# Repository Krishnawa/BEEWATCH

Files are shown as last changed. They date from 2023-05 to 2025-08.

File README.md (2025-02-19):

BEEWATCH

## Cloning the Repository and Updating Submodules  

To properly set up this project, follow these steps:  

### 1. Clone the Repository  
Use the `--recurse-submodules` flag to clone the repository along with its submodules:  

```sh
git clone --recurse-submodules https://github.com/Krishnawa/BEEWATCH.git
```
If you have already cloned the repository without submodules, initialize and update them manually:
```sh
git submodule update --init --recursive --remote
```

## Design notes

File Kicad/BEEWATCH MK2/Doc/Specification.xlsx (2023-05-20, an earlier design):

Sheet: Sheet1
ESP32-D0WDQ6 | Specifications
Processor | Dual-core Tensilica LX6 microprocessor with clock speed up to 240 MHz
Memory | 520 KB SRAM
 | 448 KB ROM
 | 8 KB RTC SRAM
WiFi | 802.11 b/g/n
 | Wi-Fi Direct (P2P), soft-AP
 | Integrated TCP/IP protocol stack
Bluetooth | Bluetooth v4.2 BR/EDR and BLE
 | Hardware acceleration for AES, SHA-2, and RSA
 | Secure boot feature
 | Flash encryption and secure flash
Peripheral interfaces | 12-bit SAR ADC up to 18 channels
 | 34 × programmable GPIOs
 | 2 × 8-bit DACs
 | 10 × touch sensors
 | 4 × SPI
 | 2 × I²C
 | 3 × UART
 | 2 × I²S
 | 16 × PWM
 | USB 2.0 (device mode only)
 | CAN 2.0
 | Ethernet MAC interface with dedicated DMA and IEEE 1588 support (available on some modules)
Power management | Internal low-dropout regulator
 | Individual power domain for RTC
 | Five different power modes
Operating temperature range | -40°C to +85°C

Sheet: Sheet3
Pin Name | Pin Number | Functionality
VDDA | 1 | Analog power supply (2.3 V ∼ 3.6 V)
LNA_IN | 2 | RF input and output
VDD3P3 | 3 | Analog power supply (2.3 V ∼ 3.6 V)
VDD3P3 | 4 | Analog power supply (2.3 V ∼ 3.6 V)
SENSOR_VP | 5 | GPIO36, ADC1_CH0, RTC_GPIO0
SENSOR_CAPP | 6 | GPIO37, ADC1_CH1, RTC_GPIO1
SENSOR_CAPN | 7 | GPIO38, ADC1_CH2, RTC_GPIO2
SENSOR_VN | 8 | GPIO39, ADC1_CH3, RTC_GPIO3
CHIP_PU | 9 | High: On; enables the chip Low: Off; the chip powers off Note: Do not leave the CHIP_PU pin floating.
VDET_1 | 10 | GPIO34, ADC1_CH6, RTC_GPIO4
VDET_2 | 11 | GPIO35, ADC1_CH7, RTC_GPIO5
32K_XP | 12 | GPIO32, ADC1_CH4, RTC_GPIO9, TOUCH9, 32K_XP (32.768 kHz crystal oscillator input)
32K_XN | 13 | GPIO33, ADC1_CH5, RTC_GPIO8, TOUCH8, 32K_XN (32.768 kHz crystal oscillator output)
GPIO25 | 14 | GPIO25, ADC2_CH8, RTC_GPIO6, DAC_1, EMAC_RXD0
GPIO26 | 15 | GPIO26, ADC2_CH9, RTC_GPIO7, DAC_2, EMAC_RXD1
GPIO27 | 16 | GPIO27, ADC2_CH7, RTC_GPIO17, TOUCH7, EMAC_RX_DV
MTMS | 17 | GPIO14, ADC2_CH6, RTC_GPIO16, TOUCH6, EMAC_TXD2, HSPICLK, HS2_CLK, SD_CLK, MTMS | CLK | Antenna out
MTDI | 18 | GPIO12, ADC2_CH5, RTC_GPIO15, TOUCH5, EMAC_TXD3, HSPIQ, HS2_DATA2, SD_DATA2, MTDI | MISO | Power input
VDD3P3_RTC | 19 | Input power supply for RTC IO (2.3 V ∼ 3.6 V) |  | Input Pin only
MTCK | 20 | GPIO13, ADC2_CH4, RTC_GPIO14, TOUCH4, EMAC_RX_ER, HSPID, HS2_DATA3, SD_DATA3, MTCK | MOSI | QSPI Flash
MTDO | 21 | GPIO15, ADC2_CH3, RTC_GPIO13, TOUCH3, EMAC_RXD3, HSPICS0. HS2_CMD, SD_CMD,MTDO | CS | RTC GPIOs, These RTC GPIOs can be used to wake up the ESP32 from deep sleep when the Ultra Low Power (ULP) co-processor is running.
GPIO2 | 22 | GPIO2, ADC2_CH2, RTC_GPIO12, TOUCH2, HSPIWP, HS2_DATA0, SD_DATA0 |  | 2 x 8 bits DAC
GPIO0 | 23 | GPIO0, ADC2_CH1, RTC_GPIO11, TOUCH1, EMAC_TX_CLK, CLK_OUT1, |  | PWM will not available
GPIO4 | 24 | GPIO4, ADC2_CH0, RTC_GPIO10, TOUCH0, EMAC_TX_ER, HSPIHD, HS2_DATA1, SD_DATA1
GPIO16 | 25 | GPIO16, HS1_DATA4, U2RXD,EMAC_CLK_OUT
VDD_SDIO | 26 | Output power supply: 1.8 V or the same voltage as VDD3P3_RTC
GPIO17 | 27 | GPIO17, HS1_DATA5, U2TXD, EMAC_CLK_OUT_180
SD_DATA_2 | 28 | GPIO9, HS1_DATA2, U1RXD, SD_DATA2, SPIHD
SD_DATA_3 | 29 | GPIO10, HS1_DATA3, U1TXD, SD_DATA3, SPIWP
IO27 | 30 | GPIO11, HS1_CMD, U1RTS, SD_CMD, SPICS0
IO34 | 31 | GPIO6, HS1_CLK, U1CTS, SD_CLK, SPICLK
SD_DATA_0 | 32 | GPIO7, HS1_DATA0, U2RTS, SD_DATA0, SPIQ
SD_DATA_1 | 33 | GPIO8, HS1_DATA1, U2CTS, SD_DATA1, SPID
GPIO5 | 34 | GPIO5, HS1_DATA6, VSPICS0, EMAC_RX_CLK
GPIO18 | 35 | GPIO18, HS1_DATA7, VSPICLK
GPIO23 | 36 | GPIO23, HS1_STROBE, VSPID
VDD3P3_CPU | 37 | Input power supply for CPU IO (1.8 V ∼ 3.6 V)
GPIO19 | 38 | GPIO19, U0CTS, VSPIQ, EMAC_TXD0
GPIO22 | 39 | GPIO22, U0RTS, VSPIWP, EMAC_TXD1
U0RXD | 40 | GPIO3, U0RXD, CLK_OUT2
U0TXD | 41 | GPIO1, U0TXD, CLK_OUT3, EMAC_RXD2
GPIO21 | 42 | GPIO21, VSPIHD, EMAC_TX_EN
VDDA | 43 | Analog power supply (2.3 V ∼ 3.6 V)
XTAL_N | 44 | External crystal output
XTAL_P | 45 | External crystal input
VDDA | 46 | Analog power supply (2.3 V ∼ 3.6 V)
CAP2 | 47 | Connects to a 3.3 nF (10%) capacitor and 20 kΩ resistor in parallel to CAP1
CAP1 | 48 | Connects to a 10 nF series capacitor to ground
GND | 49 | Ground

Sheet: Sheet2
REQ_NO | Requirement Specification | REQ_NO | REQ_NO | Requirement Specification
PRD_REQ_1 | The product shall use rounded LCD/OLED Display | PRD_REQ_1 | COMP_REQ_1 | Use GC9A01 1.28 inch 240*240 IPS LCD (SPI)
PRD_REQ_2 | The Product shall require GPS | PRD_REQ_2 | COMP_REQ_2 | Not includin in the first phase
PRD_REQ_3 | The Product shall require RTC | PRD_REQ_3 | COMP_REQ_3 | Will use Network Time Protocol
PRD_REQ_4 | In the first phase of this product need to show the time only | PRD_REQ_4 | COMP_REQ_4
PRD_REQ_5 | The Product shall require small buzzer | PRD_REQ_5 | COMP_REQ_5 | Find the PN
PRD_REQ_6 | The product shall use a chip with Wi-Fi and BT | PRD_REQ_6 | COMP_REQ_6 | will use ESP32-D0WDQ6 QFN 6*6 also find the PN
PRD_REQ_7 | The product shall have 2 push button | PRD_REQ_7 | COMP_REQ_7 | Find the PN
PRD_REQ_8 | The product shall have an accelerometer | PRD_REQ_8 | COMP_REQ_8 | MPU6050
PRD_REQ_9 | The product shall have an Temperature sensor | PRD_REQ_9 | COMP_REQ_9 | LM35
PRD_REQ_10 | The Product shall be small as Possible | PRD_REQ_10 | COMP_REQ_10 | Antenna size will be smalll
PRD_REQ_11 | The product shall have at least one week battery backup | PRD_REQ_11 | COMP_REQ_11 | 300mAh If possible
PRD_REQ_12 | The product shall have a fuel gauge | PRD_REQ_12 | COMP_REQ_12 | MAX17260,MAX17048
PRD_REQ_13 | The product shall have a charger | PRD_REQ_13 | COMP_REQ_13 | TP4056
PRD_REQ_14 | The product shall have aesthetic case | PRD_REQ_14 | COMP_REQ_14
PRD_REQ_15 |  | PRD_REQ_15 | COMP_REQ_15
PRD_REQ_16 |  | PRD_REQ_16 | COMP_REQ_16
PRD_REQ_17 |  | PRD_REQ_17 | COMP_REQ_17
PRD_REQ_18 |  | PRD_REQ_18 | COMP_REQ_18
PRD_REQ_19 |  | PRD_REQ_19 | COMP_REQ_19
PRD_REQ_20 |  | PRD_REQ_20 | COMP_REQ_20

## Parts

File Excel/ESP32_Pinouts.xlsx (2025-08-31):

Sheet: IO MUX Pin Functions
No. | Name |  |  | Type | Power | At Reset | After Reset | IO MUX | RTC | Analog
1 | LNA_IN |  |  | Analog
2 | VDD3P3 |  |  | Power
3 | VDD3P3 |  |  | Power
4 | CHIP_PU |  |  | Analog | VDD3P3_RTC |  |  |  |  |  | · IE – input enabled
5 | GPIO0 | SWITCH1 |  | IO | VDD3P3_RTC | IE, WPU | IE, WPU | IO MUX | RTC |  | · WPU – internal weak pull-up resistor enabled
6 | GPIO1 | SWITCH2 |  | IO | VDD3P3_RTC | IE | IE | IO MUX | RTC | Analog | · WPD – internal weak pull-down resistor enabled
7 | GPIO2 | BUZZER_EN |  | IO | VDD3P3_RTC | IE | IE | IO MUX | RTC | Analog | · USB_PU – USB pull-up resistor enabled
8 | GPIO3 | SDA |  | IO | VDD3P3_RTC | IE | IE | IO MUX | RTC | Analog
9 | GPIO4 | SCL |  | IO | VDD3P3_RTC |  |  | IO MUX | RTC | Analog
10 | GPIO5 | GPS ENABLE | GPS_EN | IO | VDD3P3_RTC |  |  | IO MUX | RTC | Analog
11 | GPIO6 | GPS RESET | GPS_RST | IO | VDD3P3_RTC |  |  | IO MUX | RTC | Analog
12 | GPIO7 | 1PPS | GPS_PPS | IO | VDD3P3_RTC |  |  | IO MUX | RTC | Analog
13 | GPIO8 | Display | RST | IO | VDD3P3_RTC |  |  | IO MUX | RTC | Analog | ide of the digital an
14 | GPIO9 | Display | DC | IO | VDD3P3_RTC |  | IE | IO MUX | RTC | Analog
15 | GPIO10 | Display | CS | IO | VDD3P3_RTC |  | IE | IO MUX | RTC | Analog
16 | GPIO11 | Display | MOSI | IO | VDD3P3_RTC |  | IE | IO MUX | RTC | Analog
17 | GPIO12 | Display | SCK | IO | VDD3P3_RTC |  | IE | IO MUX | RTC | Analog
18 | GPIO13 | mpu interrupt | MPU_INT | IO | VDD3P3_RTC |  | IE | IO MUX | RTC | Analog
19 | GPIO14 | BAT_VSENSE |  | IO | VDD3P3_RTC |  | IE | IO MUX | RTC | Analog
20 | VDD3P3_RTC |  |  | Power
21 | XTAL_32K_P | XTAL | rtc | IO | VDD3P3_RTC |  |  | IO MUX | RTC | Analog
22 | XTAL_32K_N | XTAL | rtc | IO | VDD3P3_RTC |  |  | IO MUX | RTC | Analog
23 | GPIO17 | GPS RX |  | IO | VDD3P3_RTC |  | IE | IO MUX | RTC | Analog
24 | GPIO18 | GPS TX |  | IO | VDD3P3_RTC |  | IE | IO MUX | RTC | Analog
25 | GPIO19 | USB+ |  | IO | VDD3P3_RTC |  |  | IO MUX | RTC | Analog
26 | GPIO20 | USB- |  | IO | VDD3P3_RTC | USB_PU | USB_PU | IO MUX | RTC | Analog
27 | GPIO21 | LED2 |  | IO | VDD3P3_RTC |  |  | IO MUX | RTC
28 | SPICS1 |  |  | IO | VDD_SPI | IE, WPU | IE, WPU | IO MUX
29 | VDD_SPI |  |  | Power
30 | SPIHD |  |  | IO | VDD_SPI | IE, WPU | IE, WPU | IO MUX
31 | SPIWP |  |  | IO | VDD_SPI | IE, WPU | IE, WPU | IO MUX
32 | SPICS0 |  |  | IO | VDD_SPI | IE, WPU | IE, WPU | IO MUX
33 | SPICLK |  |  | IO | VDD_SPI | IE, WPU | IE, WPU | IO MUX
34 | SPIQ |  |  | IO | VDD_SPI | IE, WPU | IE, WPU | IO MUX
35 | SPID |  |  | IO | VDD_SPI | IE, WPU | IE, WPU | IO MUX
36 | SPICLK_N |  |  | IO | VDD_SPI / VDD3P3_CPU | IE | IE | IO MUX
37 | SPICLK_P |  |  | IO | VDD_SPI / VDD3P3_CPU | IE | IE | IO MUX
38 | GPIO33 |  |  | IO | VDD_SPI / VDD3P3_CPU |  | IE | IO MUX
39 | GPIO34 | PWR SENSE |  | IO | VDD_SPI / VDD3P3_CPU |  | IE | IO MUX
40 | GPIO35 | BUZZER |  | IO | VDD_SPI / VDD3P3_CPU |  | IE | IO MUX
41 | GPIO36 |  |  | IO | VDD_SPI / VDD3P3_CPU |  | IE | IO MUX
42 | GPIO37 |  |  | IO | VDD_SPI / VDD3P3_CPU |  | IE | IO MUX
43 | GPIO38 |  |  | IO | VDD3P3_CPU |  | IE | IO MUX
44 | MTCK |  |  | IO | VDD3P3_CPU |  | IE | IO MUX
45 | MTDO |  |  | IO | VDD3P3_CPU |  | IE | IO MUX
46 | VDD3P3_CPU |  |  | Power
47 | MTDI |  |  | IO | VDD3P3_CPU |  | IE | IO MUX
48 | MTMS |  |  | IO | VDD3P3_CPU |  | IE | IO MUX
49 | U0TXD |  |  | IO | VDD3P3_CPU | IE, WPU | IE, WPU | IO MUX
50 | U0RXD |  |  | IO | VDD3P3_CPU | IE, WPU | IE, WPU | IO MUX
51 | GPIO45 |  |  | IO | VDD3P3_CPU | IE, WPD | IE, WPD | IO MUX
52 | GPIO46 |  |  | IO | VDD3P3_CPU | IE, WPD | IE, WPD | IO MUX
53 | XTAL_N | Crystal |  | Analog
54 | XTAL_P | Crystal |  | Analog
55 | VDDA |  |  | Power
56 | VDDA |  |  | Power
57 | GND |  |  | Power

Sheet: Sheet1
https://chatgpt.com/share/6789162e-64f8-800f-9e0a-48cd8099282f
OPEN TERACE | $GPRMC,155304.00,A,1259.7372,N,07743.0398,E,0.0,0.0,160125,,,A,V*28
CLOSED ROOM | $GNRMC,162906.00,V,1259.7389,N,07743.0415,E,,,160125,,,N,V*24

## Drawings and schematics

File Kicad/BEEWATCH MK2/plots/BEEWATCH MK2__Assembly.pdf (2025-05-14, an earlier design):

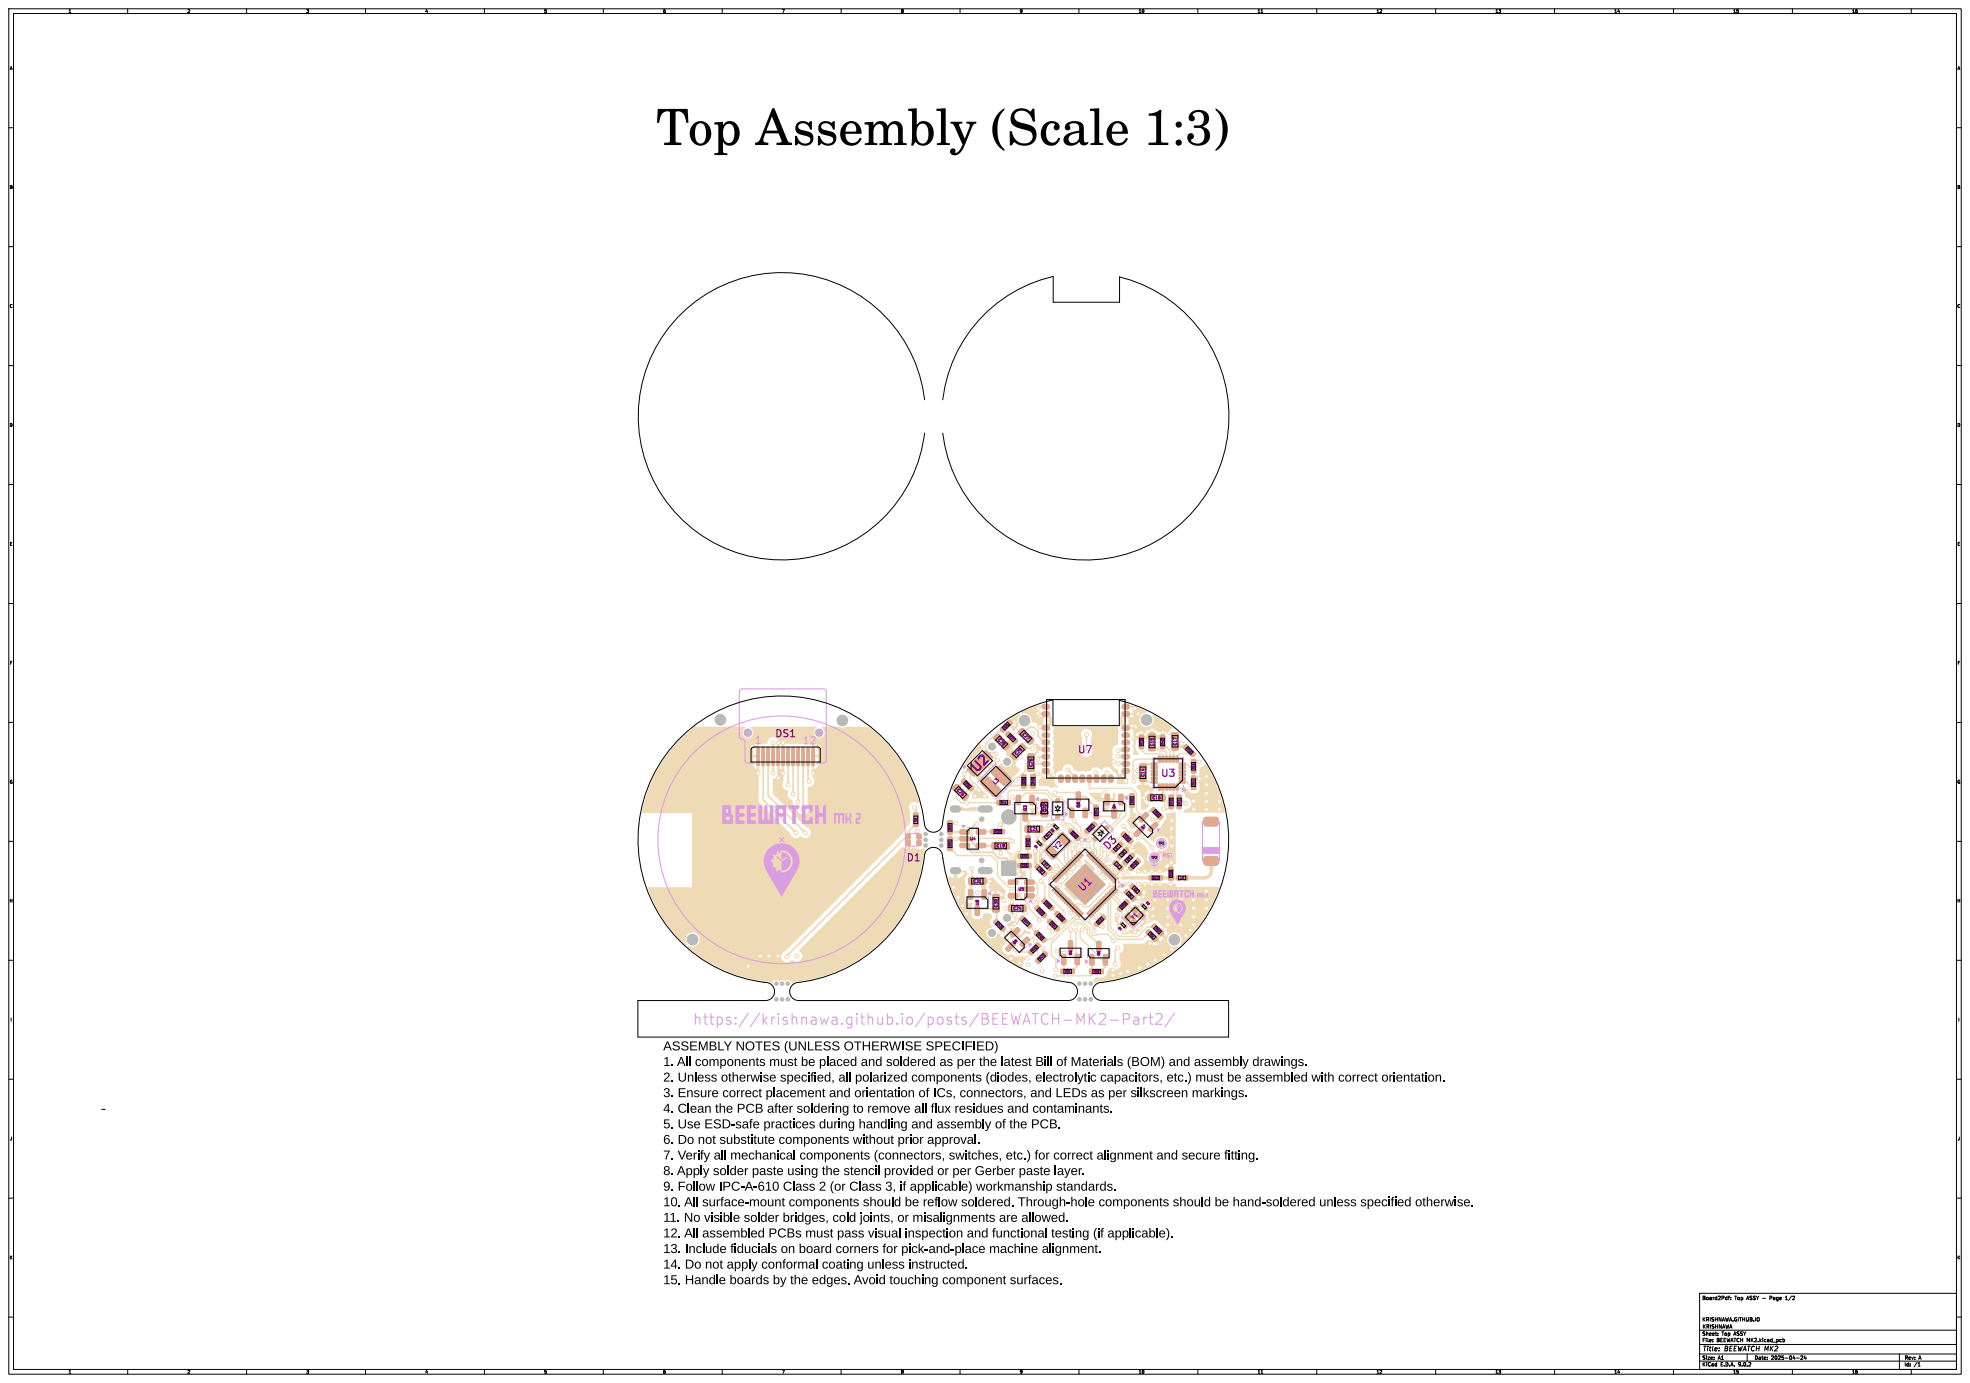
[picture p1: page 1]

RST https://krishnawa.github.io/posts/BEEWATCH-MK2-Part2/

KRISHNAWA.GITHUB.IO
File: BEEWATCH MK2.kicad_pcb Sheet: Top ASSY KRISHNAWA

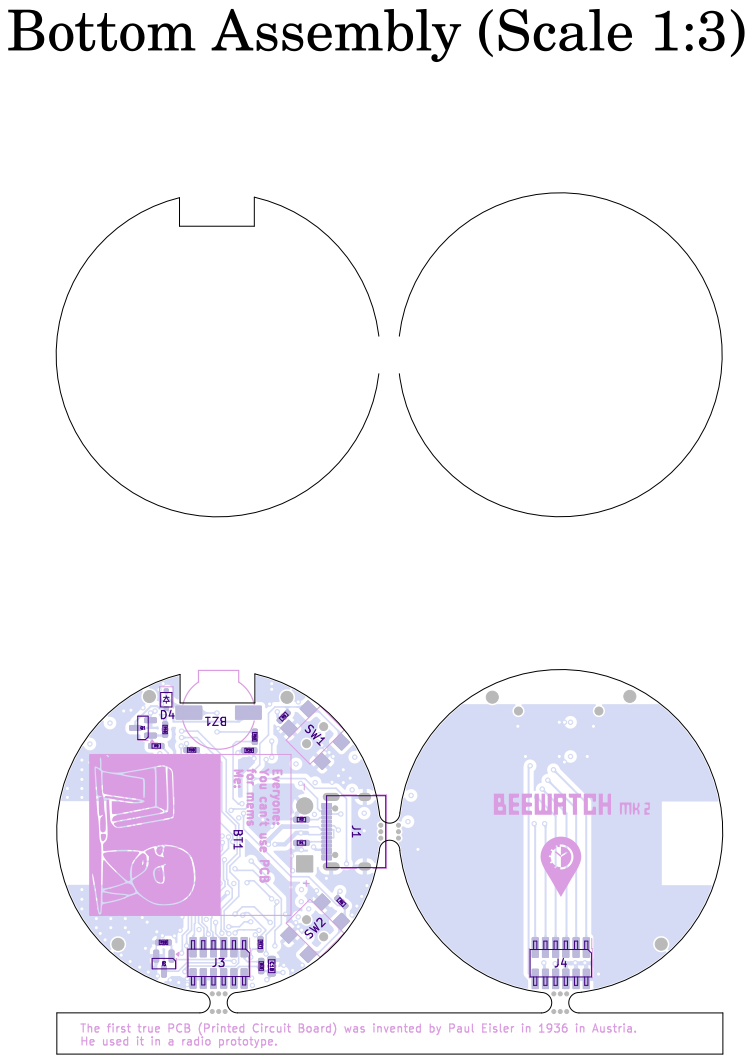
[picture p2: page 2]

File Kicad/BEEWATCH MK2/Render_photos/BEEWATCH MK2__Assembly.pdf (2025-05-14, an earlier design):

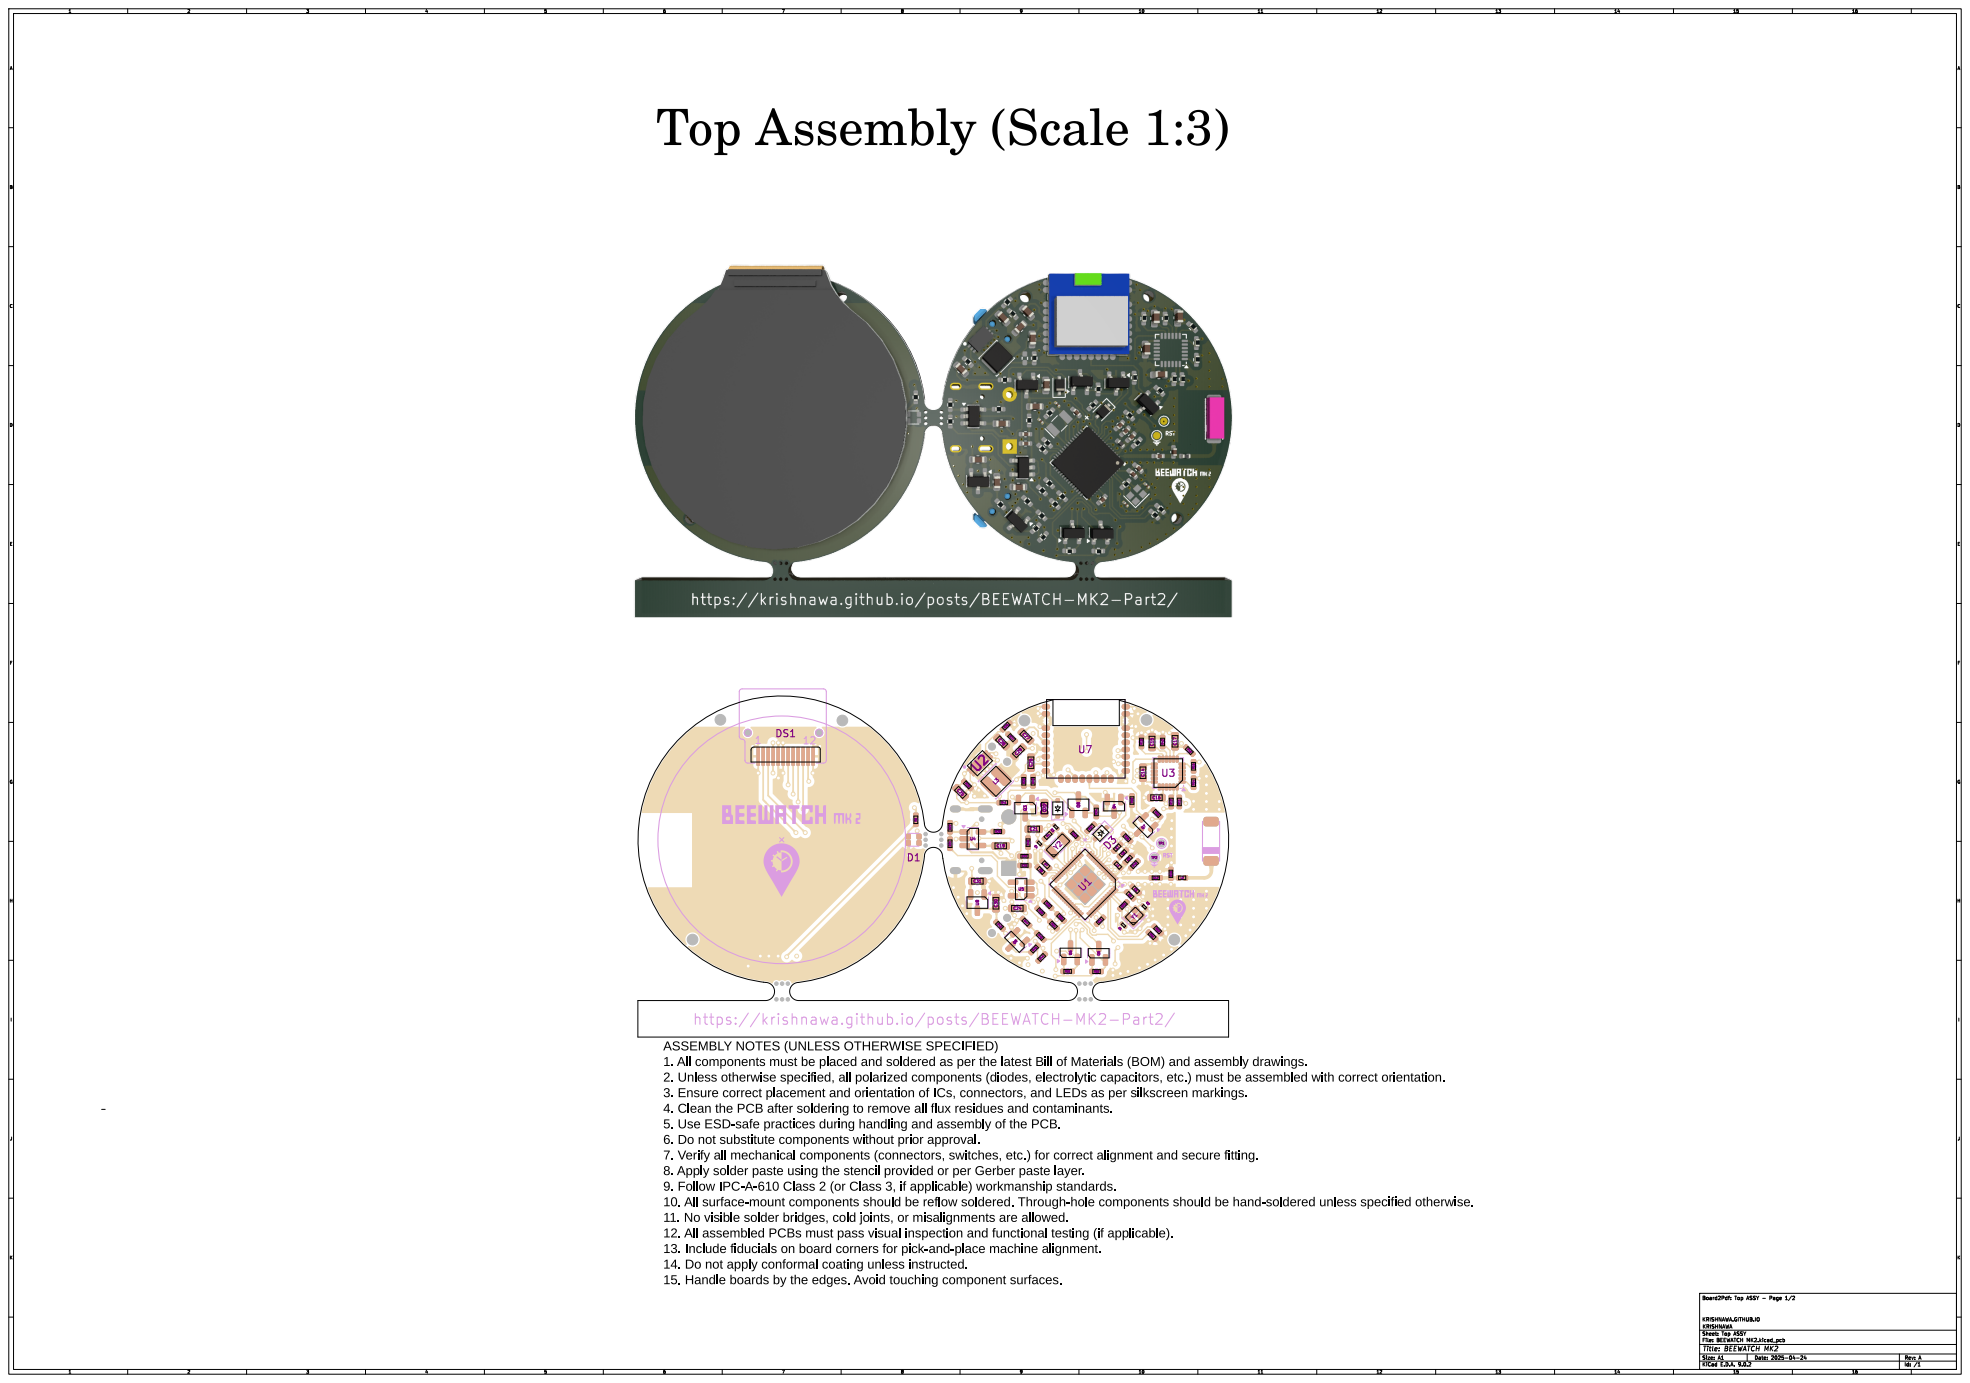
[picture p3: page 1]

RST https://krishnawa.github.io/posts/BEEWATCH-MK2-Part2/

KRISHNAWA.GITHUB.IO
File: BEEWATCH MK2.kicad_pcb Sheet: Top ASSY KRISHNAWA

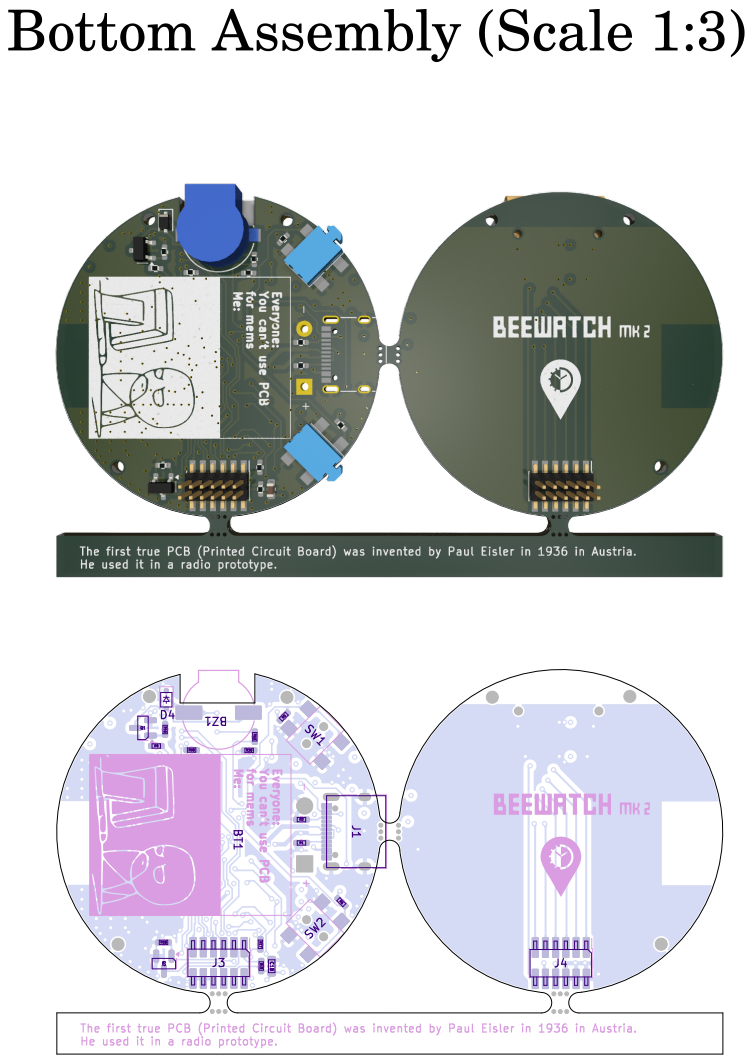
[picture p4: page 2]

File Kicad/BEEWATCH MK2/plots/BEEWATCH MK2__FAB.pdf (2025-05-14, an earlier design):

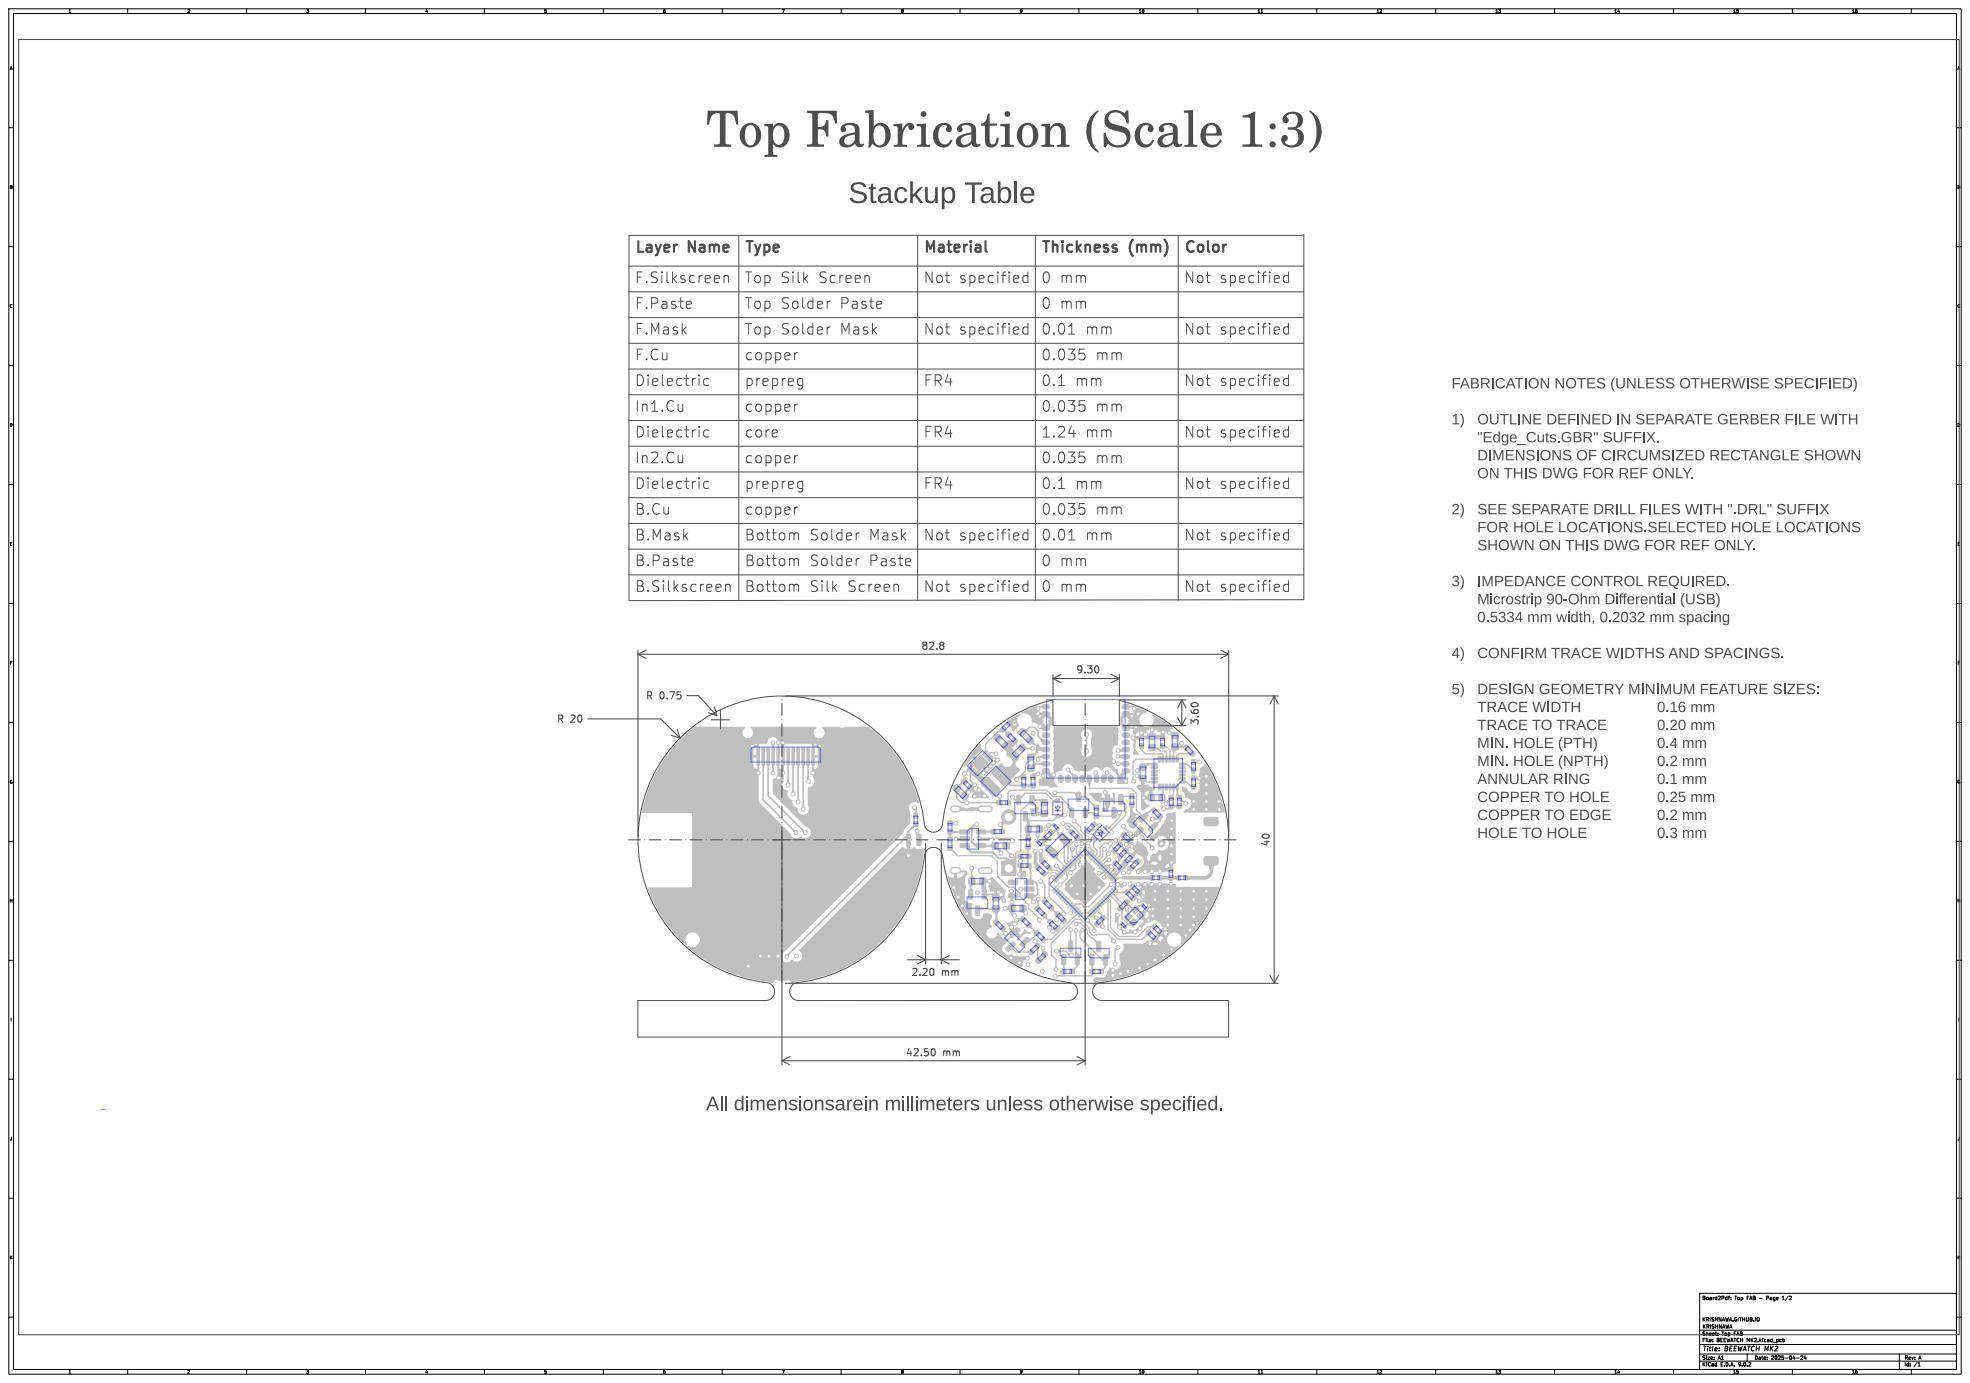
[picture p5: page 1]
IJK; IJK Date: 2025-04-24 KiCad; E.D.A. 9.0.2 Size: A1; Rev: A; File: BEEWATCH; MK2.kicad_pcb Sheet: Top; FAB KRISHNAWA; Board2Pdf:; Top; FAB -; Page; Bottom; Silk; Screen; Solder; Mask; Top Solder; prepreg; In1.Cu Dielectric; Not; specified; copper

Layer Name
F.Silkscreen | Top Silk Screen F.Mask | Not specified | 0.1 mm

prepreg F.Paste | | 1.24 mm | Not Not Color Top Solder Paste Not specified specified Material specified Dielectric

Type | Not specified | Thickness | (mm) 0.01 mm | Not specified

Dielectric F.Cu B.Silkscreen | copper | | 0 mm

core | 0.035 mm | Not specified

copper B.Mask | | | | | 0.1 mm

B.Cu | | | 0.035 mm | Not specified

Not specified Bottom Solder Paste | 0.01 mm

B.Paste | | | | | 0 mm

Not specified

KRISHNAWA.GITHUB.IO

Id: /1 Title: BEEWATCH MK2

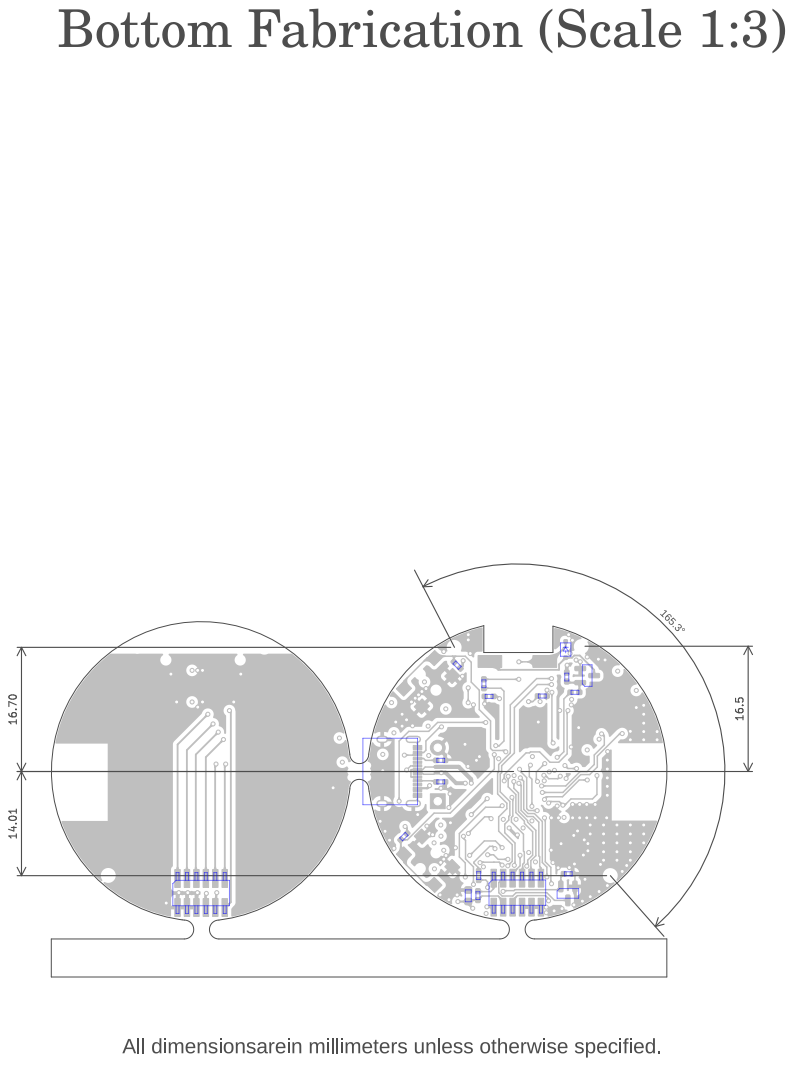
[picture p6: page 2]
IJK; IJK Date: 2025-04-24 KiCad; E.D.A. 9.0.2 Size: A1; Rev: A; File: BEEWATCH; MK2.kicad_pcb Sheet: Bttom; FAB KRISHNAWA; Board2Pdf:; Bttom; FAB -; Page 2/2 14.01

KRISHNAWA.GITHUB.IO

Id: /1 Title: BEEWATCH MK2

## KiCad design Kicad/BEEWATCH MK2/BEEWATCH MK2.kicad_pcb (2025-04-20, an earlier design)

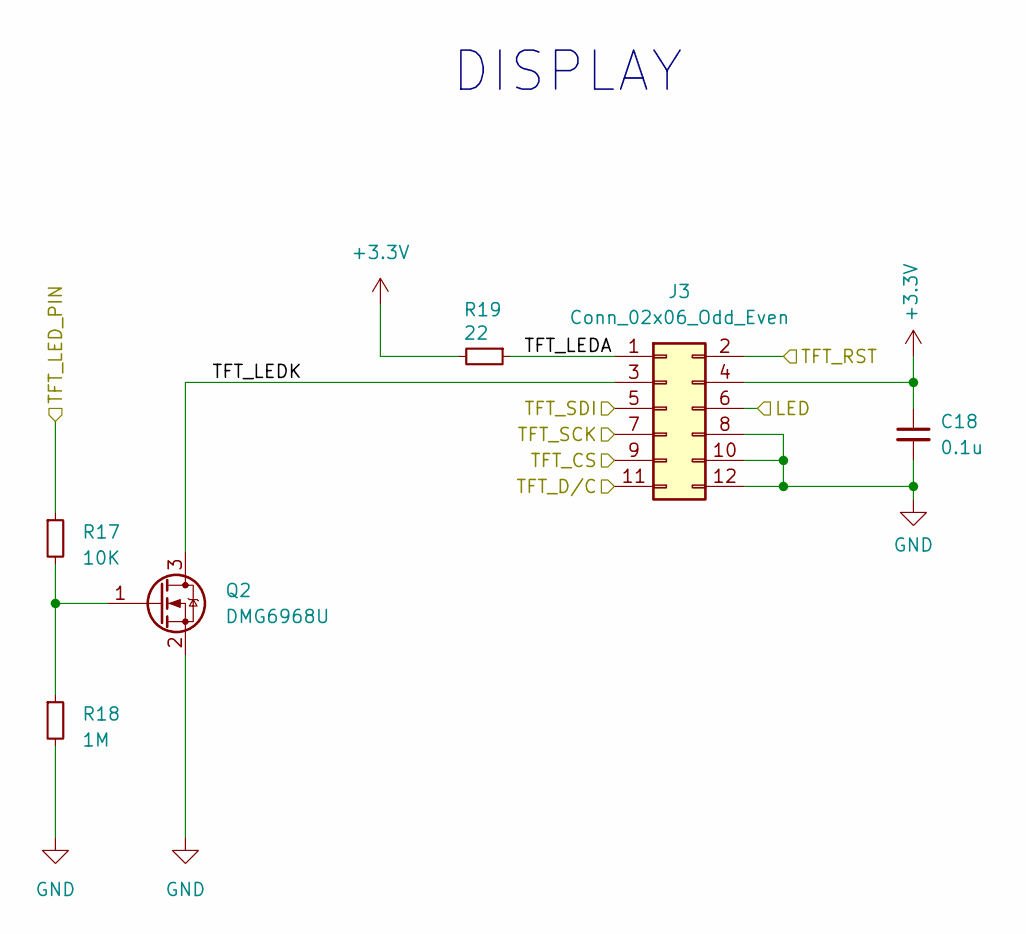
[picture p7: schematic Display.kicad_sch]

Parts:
C18: 0.1u; C_0603_1608Metric
J3: Conn_02x06_Odd_Even; PinHeader_2x06_P1.27mm_Vertical_SMD
Q2: DMG6968U; SOT-23
R17: 10K; R_0402_1005Metric_Pad0.72x0.64mm_HandSolder
R18: 1M; R_0402_1005Metric_Pad0.72x0.64mm_HandSolder
R19: 22; R_0402_1005Metric_Pad0.72x0.64mm_HandSolder

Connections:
+3.3V: C18.1, J3.4, R19.2; also elsewhere on the board
/Display/LED: J3.6; also elsewhere on the board
/Display/TFT_CS: J3.9; also elsewhere on the board
/Display/TFT_D/C: J3.11; also elsewhere on the board
/Display/TFT_LEDA: J3.1, R19.1
/Display/TFT_LEDK: J3.3, Q2.3 (D)
/Display/TFT_LED_PIN: R17.1; also elsewhere on the board
/Display/TFT_RST: J3.2; also elsewhere on the board
/Display/TFT_SCK: J3.7; also elsewhere on the board
/Display/TFT_SDI: J3.5; also elsewhere on the board
GND: C18.2, J3.8, J3.10, J3.12, Q2.2 (S), R18.2; also elsewhere on the board
unnamed: Q2.1 (G), R17.2, R18.1

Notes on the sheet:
DISPLAY

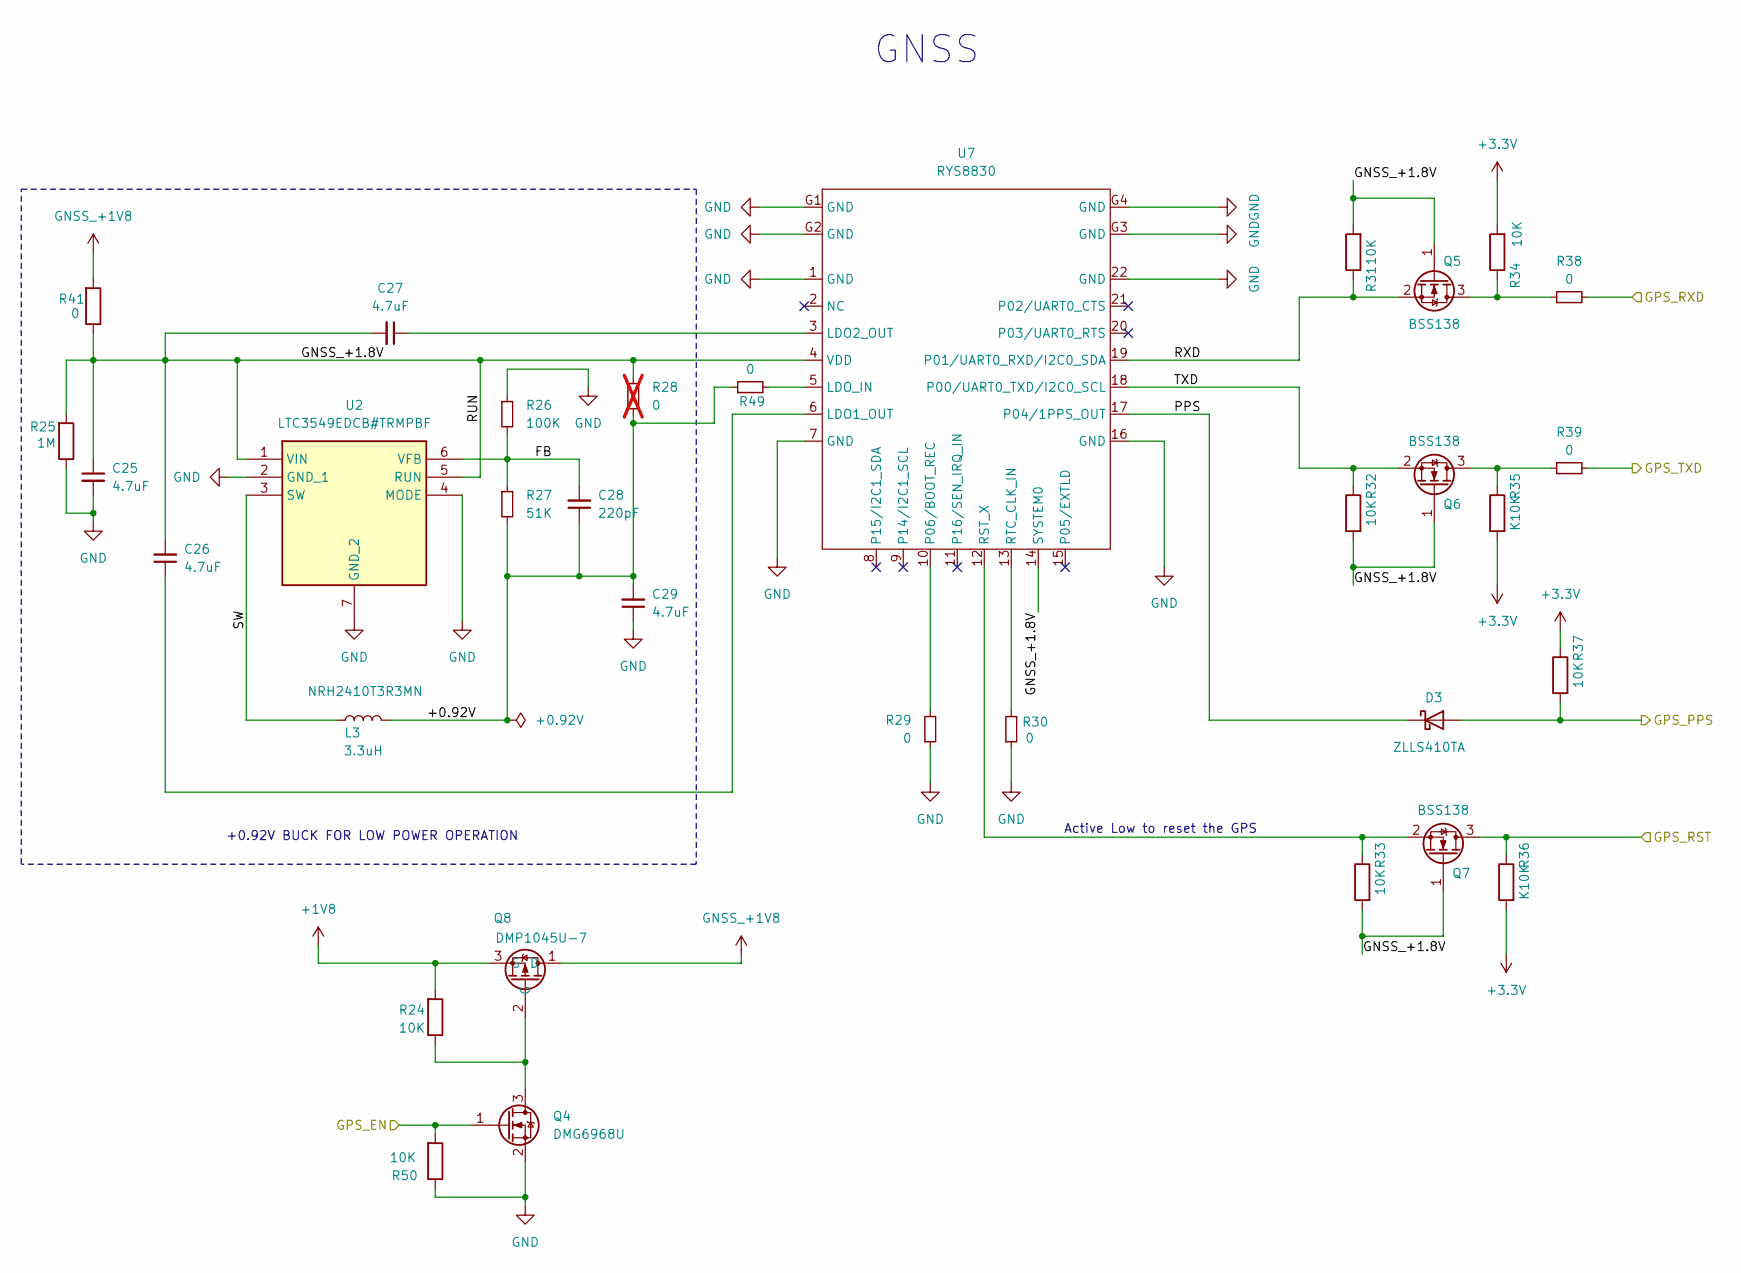
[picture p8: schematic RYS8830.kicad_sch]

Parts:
C25, C26, C27, C29: 4.7uF; C_0603_1608Metric
C28: 220pF; C_0603_1608Metric
D3: ZLLS410TA; D_SOD-323F
L3: 3.3uH; L_Cenker_CKCS3012; MPN NRH2410T3R3MN
Q4: DMG6968U; SOT-23
Q5, Q6, Q7: BSS138; SOT-23
Q8: DMP1045U-7; SOT-23-3
R24, R31, R32, R33, R34, R37, R50: 10K; R_0402_1005Metric_Pad0.72x0.64mm_HandSolder
R25: 1M; R_0402_1005Metric_Pad0.72x0.64mm_HandSolder
R26: 100K; R_0402_1005Metric_Pad0.72x0.64mm_HandSolder
R27: 51K; R_0402_1005Metric_Pad0.72x0.64mm_HandSolder
R28: 0; R_0402_1005Metric_Pad0.72x0.64mm_HandSolder; not fitted
R29, R30, R38, R39, R41, R49: 0; R_0402_1005Metric_Pad0.72x0.64mm_HandSolder
R35, R36: K10K; R_0402_1005Metric_Pad0.72x0.64mm_HandSolder
U2: LTC3549EDCB#TRMPBF; SON50P300X200X80-7N-D
U7: RYS8830

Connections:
+1V8: Q8.3 (S), R24.2; also elsewhere on the board
+3.3V: R34.2, R35.2, R36.2, R37.1; also elsewhere on the board
/ESP32/GPS_EN: Q4.1 (G), R50.2; also elsewhere on the board
/ESP32/GPS_PSS: D3.2 (A), R37.2; also elsewhere on the board
/ESP32/GPS_RST: Q7.3 (D), R36.1; also elsewhere on the board
/ESP32/GPS_RXD: R39.2; also elsewhere on the board
/ESP32/GPS_TXD: R38.2; also elsewhere on the board
/RYS8830/+0.92V: C28.1, C29.2, L3.2, R27.2, R28.2, R49.1
/RYS8830/FB: C28.2, R26.2, R27.1, U2.6 (VFB)
/RYS8830/GNSS_+1.8V: C25.1, C26.2, C27.2, Q5.1 (G), Q6.1 (G), Q7.1 (G), R25.2, R28.1, R31.2, R32.2, R33.2, R41.1, U2.1 (VIN), U2.5 (RUN), U7.4 (VDD), U7.14 (SYSTEM0)
/RYS8830/PPS: D3.1 (K), U7.17 (P04/1PPS_OUT)
/RYS8830/RXD: Q5.2 (S), R31.1, U7.19 (P01/UART0_RXD/I2C0_SDA)
/RYS8830/SW: L3.1, U2.3 (SW)
/RYS8830/TXD: Q6.2 (S), R32.1, U7.18 (P00/UART0_TXD/I2C0_SCL)
GND: C25.2, C29.1, Q4.2 (S), R25.1, R26.1, R29.1, R30.1, R50.1, U2.2 (GND_1), U2.4 (MODE), U2.7 (GND_2), U7.1 (GND), U7.7 (GND), U7.16 (GND), U7.22 (GND), U7.G1 (GND), U7.G2 (GND), U7.G3 (GND), U7.G4 (GND); also elsewhere on the board
GNSS_+1V8: Q8.1 (D), R41.2
unnamed: Q4.3 (D), Q8.2 (G), R24.1
unnamed: Q5.3 (D), R34.1, R38.1
unnamed: Q6.3 (D), R35.1, R39.1
unnamed: Q7.2 (S), R33.1, U7.12 (RST_X)
unnamed: C26.1, U7.6 (LDO1_OUT)
unnamed: C27.1, U7.3 (LDO2_OUT)
unnamed: R49.2, U7.5 (LDO_IN)
unnamed: R29.2, U7.10 (P06/BOOT_REC)
unnamed: R30.2, U7.13 (RTC_CLK_IN)

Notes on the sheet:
GNSS
Active Low to reset the GPS
+0.92V BUCK FOR LOW POWER OPERATION

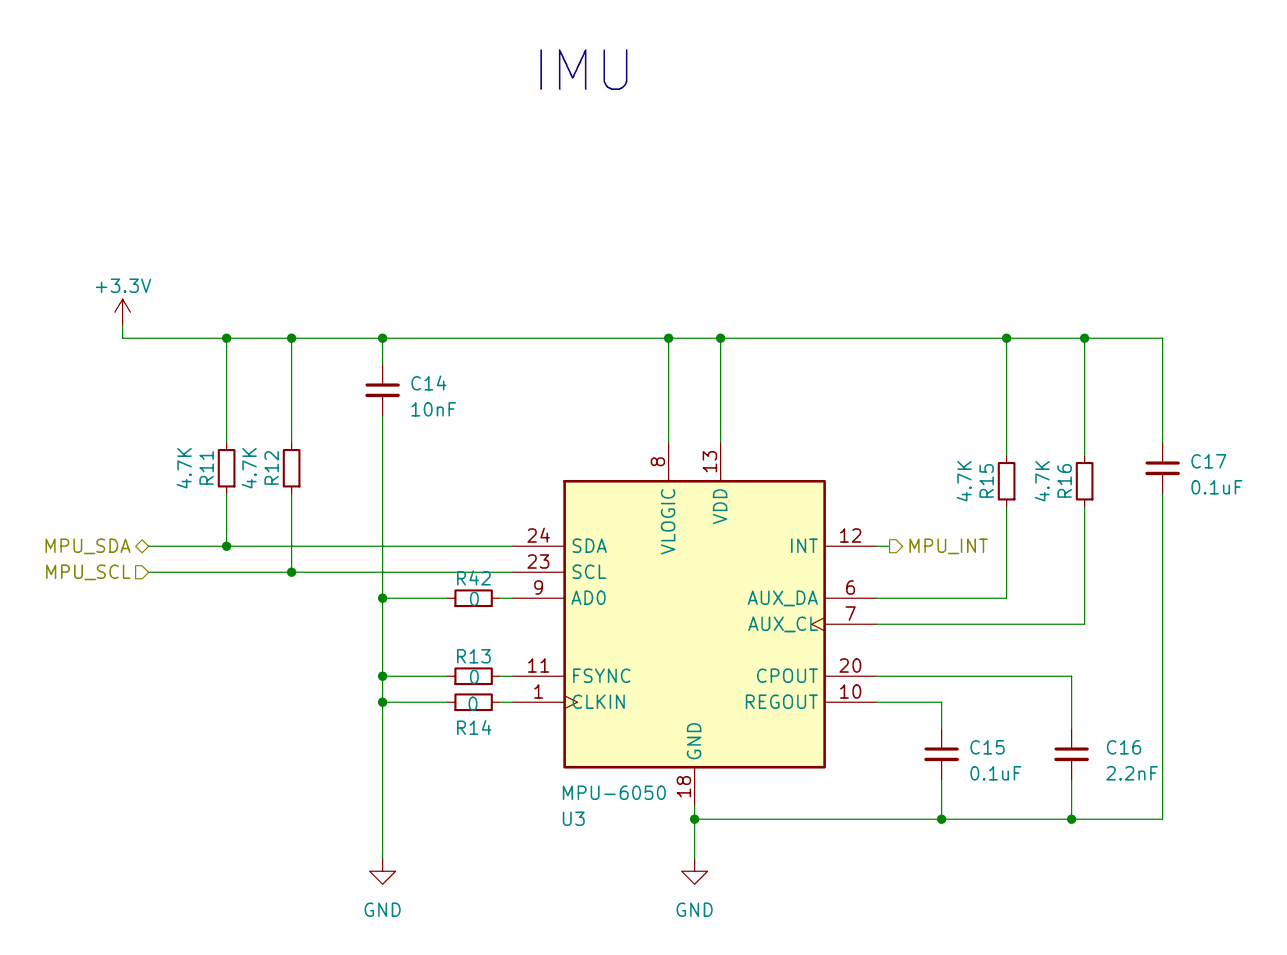
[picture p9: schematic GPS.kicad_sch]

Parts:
C14: 10nF; C_0603_1608Metric
C15, C17: 0.1uF; C_0603_1608Metric
C16: 2.2nF; C_0603_1608Metric
R11, R12, R15, R16: 4.7K; R_0402_1005Metric_Pad0.72x0.64mm_HandSolder
R13, R14, R42: 0; R_0402_1005Metric_Pad0.72x0.64mm_HandSolder
U3: MPU-6050; InvenSense_QFN-24_4x4mm_P0.5mm

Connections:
+3.3V: C14.1, C17.1, R11.2, R12.2, R15.2, R16.2, U3.8 (VLOGIC), U3.13 (VDD); also elsewhere on the board
/ACCELEROMETER/MPU_INT: U3.12 (INT); also elsewhere on the board
/ACCELEROMETER/MPU_SCL: R12.1, U3.23 (SCL); also elsewhere on the board
/ACCELEROMETER/MPU_SDA: R11.1, U3.24 (SDA); also elsewhere on the board
GND: C14.2, C15.2, C16.2, C17.2, R13.1, R14.1, R42.1, U3.18 (GND); also elsewhere on the board
unnamed: R42.2, U3.9 (AD0)
unnamed: R16.1, U3.7 (AUX_CL)
unnamed: R15.1, U3.6 (AUX_DA)
unnamed: R14.2, U3.1 (CLKIN)
unnamed: C16.1, U3.20 (CPOUT)
unnamed: R13.2, U3.11 (FSYNC)
unnamed: C15.1, U3.10 (REGOUT)

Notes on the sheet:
IMU

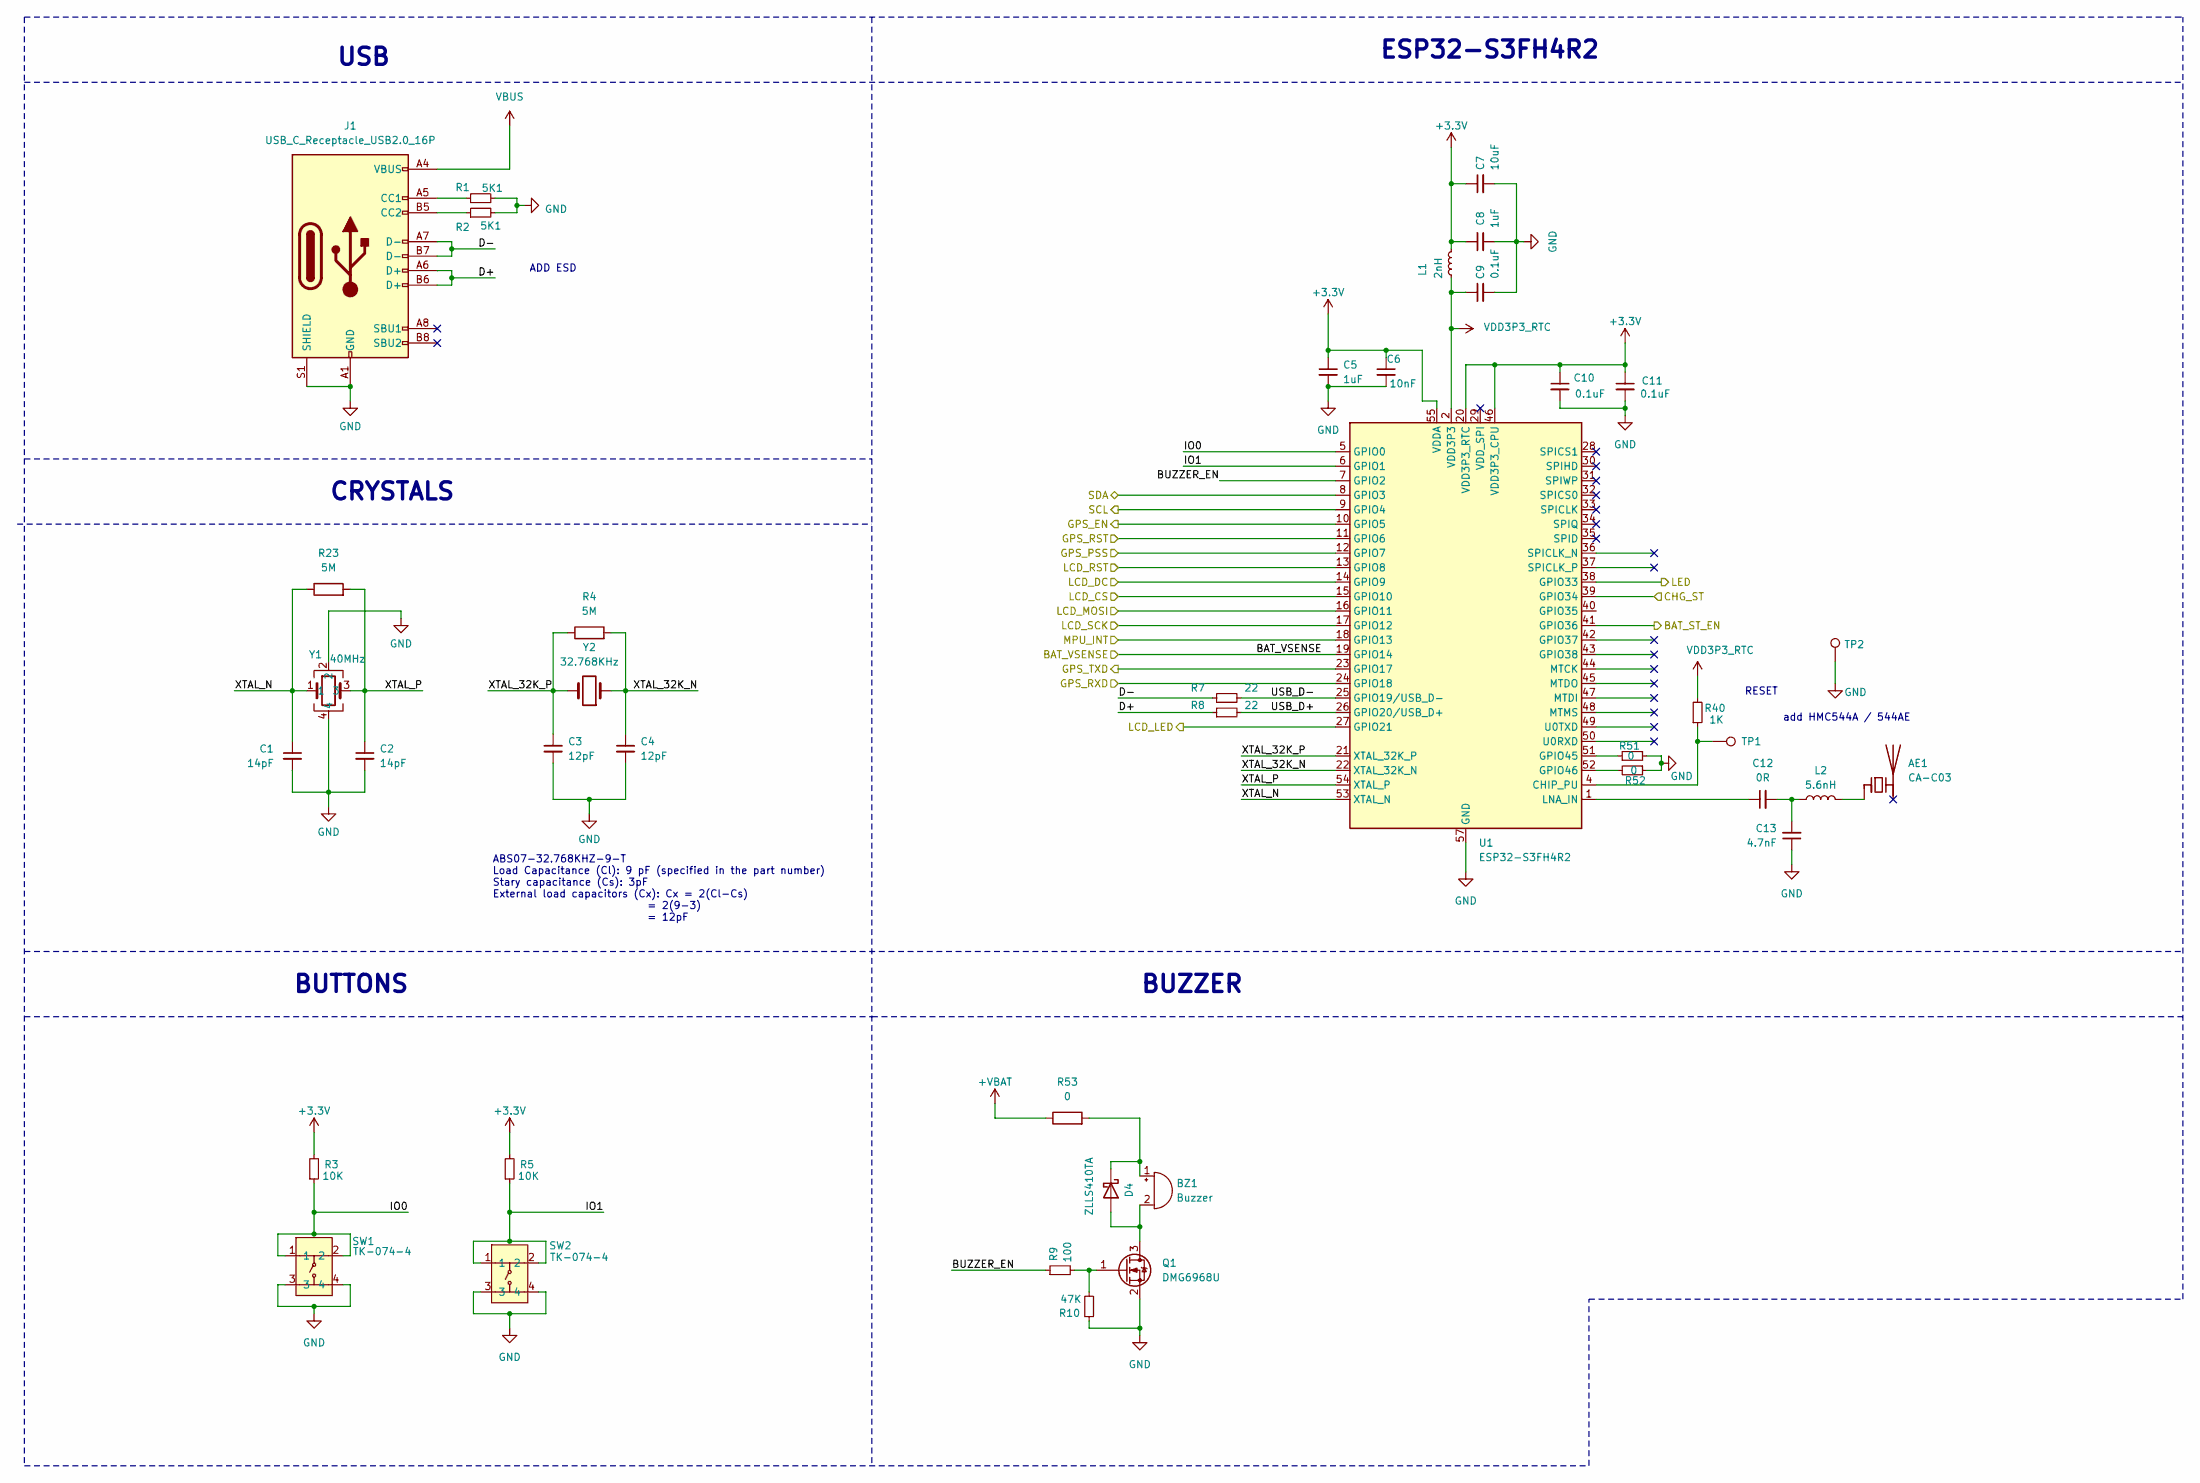
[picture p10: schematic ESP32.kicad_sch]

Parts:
AE1: CA-C03; ESP32_ZERO_ANT
BZ1: Buzzer; CL9032A-CLDZ-SMD Passive Buzzer
C1, C2: 14pF; C_0201_0603Metric
C3, C4: 12pF; C_0201_0603Metric
C5, C8: 1uF; C_0402_1005Metric_Pad0.74x0.62mm_HandSolder
C6: 10nF; C_0402_1005Metric_Pad0.74x0.62mm_HandSolder
C7: 10uF; C_0402_1005Metric_Pad0.74x0.62mm_HandSolder
C9, C10, C11: 0.1uF; C_0402_1005Metric_Pad0.74x0.62mm_HandSolder
C12: 0R; C_0402_1005Metric_Pad0.74x0.62mm_HandSolder
C13: 4.7nF; C_0402_1005Metric_Pad0.74x0.62mm_HandSolder
D4: ZLLS410TA; D_SOD-323F
J1: USB_C_Receptacle_USB2.0_16P; USB_C_Receptacle_XKB_U262-16XN-4BVC11
L1: 2nH; L_0402_1005Metric
L2: 5.6nH; L_0402_1005Metric
Q1: DMG6968U; SOT-23
R1, R2: 5K1; R_0402_1005Metric_Pad0.72x0.64mm_HandSolder
R3, R5: 10K; R_0402_1005Metric_Pad0.72x0.64mm_HandSolder
R4, R23: 5M; R_0402_1005Metric_Pad0.72x0.64mm_HandSolder
R7, R8: 22; R_0402_1005Metric_Pad0.72x0.64mm_HandSolder
R9: 100; R_0402_1005Metric_Pad0.72x0.64mm_HandSolder
R10: 47K; R_0402_1005Metric_Pad0.72x0.64mm_HandSolder
R40: 1K; R_0402_1005Metric_Pad0.72x0.64mm_HandSolder
R51, R52, R53: 0; R_0402_1005Metric_Pad0.72x0.64mm_HandSolder
SW1, SW2: TK-074-4; Tact Switch-TK-074-4 Pin SMD
TP1, TP2: TestPoint; TestPoint_Pad_D1.0mm
U1: ESP32-S3FH4R2; QFN-56-1EP_7x7mm_P0.4mm_EP4x4mm
Y1: 40MHz; Crystal_SMD_2016-4Pin_2.0x1.6mm
Y2: 32.768KHz; Crystal_SMD_EuroQuartz_EQ161-2Pin_3.2x1.5mm

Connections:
+3.3V: C5.1, C6.1, C7.1, C8.1, C10.1, C11.1, L1.2, R3.2, R5.2, U1.20 (VDD3P3_RTC), U1.46 (VDD3P3_CPU), U1.55 (VDDA), U1.56 (VDDA); also elsewhere on the board
+VBAT: R53.1; also elsewhere on the board
/ACCELEROMETER/MPU_INT: U1.18 (GPIO13); also elsewhere on the board
/ACCELEROMETER/MPU_SCL: U1.9 (GPIO4); also elsewhere on the board
/ACCELEROMETER/MPU_SDA: U1.8 (GPIO3); also elsewhere on the board
/Battery&BMS/BAT_SENSE_EN: U1.41 (GPIO36); also elsewhere on the board
/Battery&BMS/CHG_ST: U1.39 (GPIO34); also elsewhere on the board
/Display/LED: U1.38 (GPIO33); also elsewhere on the board
/Display/TFT_CS: U1.15 (GPIO10); also elsewhere on the board
/Display/TFT_D/C: U1.14 (GPIO9); also elsewhere on the board
/Display/TFT_LED_PIN: U1.27 (GPIO21); also elsewhere on the board
/Display/TFT_RST: U1.13 (GPIO8); also elsewhere on the board
/Display/TFT_SCK: U1.17 (GPIO12); also elsewhere on the board
/Display/TFT_SDI: U1.16 (GPIO11); also elsewhere on the board
/ESP32/BAT_VSENSE: U1.19 (GPIO14); also elsewhere on the board
/ESP32/BUZZER_EN: R9.1, U1.7 (GPIO2)
/ESP32/D+: J1.A6 (D+), J1.B6 (D+), R8.1
/ESP32/D-: J1.A7 (D-), J1.B7 (D-), R7.1
/ESP32/GPS_EN: U1.10 (GPIO5); also elsewhere on the board
/ESP32/GPS_PSS: U1.12 (GPIO7); also elsewhere on the board
/ESP32/GPS_RST: U1.11 (GPIO6); also elsewhere on the board
/ESP32/GPS_RXD: U1.24 (GPIO18); also elsewhere on the board
/ESP32/GPS_TXD: U1.23 (GPIO17); also elsewhere on the board
/ESP32/IO0: R3.1, SW1.1, SW1.2, U1.5 (GPIO0)
/ESP32/IO1: R5.1, SW2.1, SW2.2, U1.6 (GPIO1)
/ESP32/USB_D+: R8.2, U1.26 (GPIO20/USB_D+)
/ESP32/USB_D-: R7.2, U1.25 (GPIO19/USB_D-)
/ESP32/XTAL_32K_N: C4.1, R4.2, U1.22 (XTAL_32K_N), Y2.1
/ESP32/XTAL_32K_P: C3.1, R4.1, U1.21 (XTAL_32K_P), Y2.2
/ESP32/XTAL_N: C1.1, R23.1, U1.53 (XTAL_N), Y1.1
/ESP32/XTAL_P: C2.1, R23.2, U1.54 (XTAL_P), Y1.3
GND: C1.2, C2.2, C3.2, C4.2, C5.2, C6.2, C7.2, C8.2, C9.2, C10.2, C11.2, C13.1, J1.A1 (GND), J1.A12 (GND), J1.B1 (GND), J1.B12 (GND), J1.S1 (SHIELD), Q1.2 (S), R1.2, R2.2, R10.1, R51.2, R52.1, SW1.3, SW1.4, SW2.3, SW2.4, TP2.1, U1.57 (GND), Y1.2, Y1.4; also elsewhere on the board
unnamed: AE1.1 (FEED), L2.2
unnamed: BZ1.1 (+), D4.1 (K), R53.2
unnamed: BZ1.2 (-), D4.2 (A), Q1.3 (D)
unnamed: C12.2, C13.2, L2.1
unnamed: J1.A5 (CC1), R1.1
unnamed: J1.B5 (CC2), R2.1
unnamed: Q1.1 (G), R9.2, R10.2
unnamed: R40.1, TP1.1, U1.4 (CHIP_PU)
unnamed: R51.1, U1.51 (GPIO45)
unnamed: R52.2, U1.52 (GPIO46)
unnamed: C12.1, U1.1 (LNA_IN)
VBUS: J1.A4 (VBUS), J1.A9 (VBUS), J1.B4 (VBUS), J1.B9 (VBUS); also elsewhere on the board
VDD3P3_RTC: C9.1, L1.1, R40.2, U1.2 (VDD3P3), U1.3 (VDD3P3)

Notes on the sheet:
BUZZER
USB
CRYSTALS
BUTTONS
RESET
ESP32-S3FH4R2
add HMC544A / 544AE
ABS07-32.768KHZ-9-T Load Capacitance (Cl): 9 pF (specified in the part number) Stary capacitance (Cs): 3pF External load capacitors (Cx): Cx = 2(Cl-Cs) = 2(9-3) = 12pF
ADD ESD

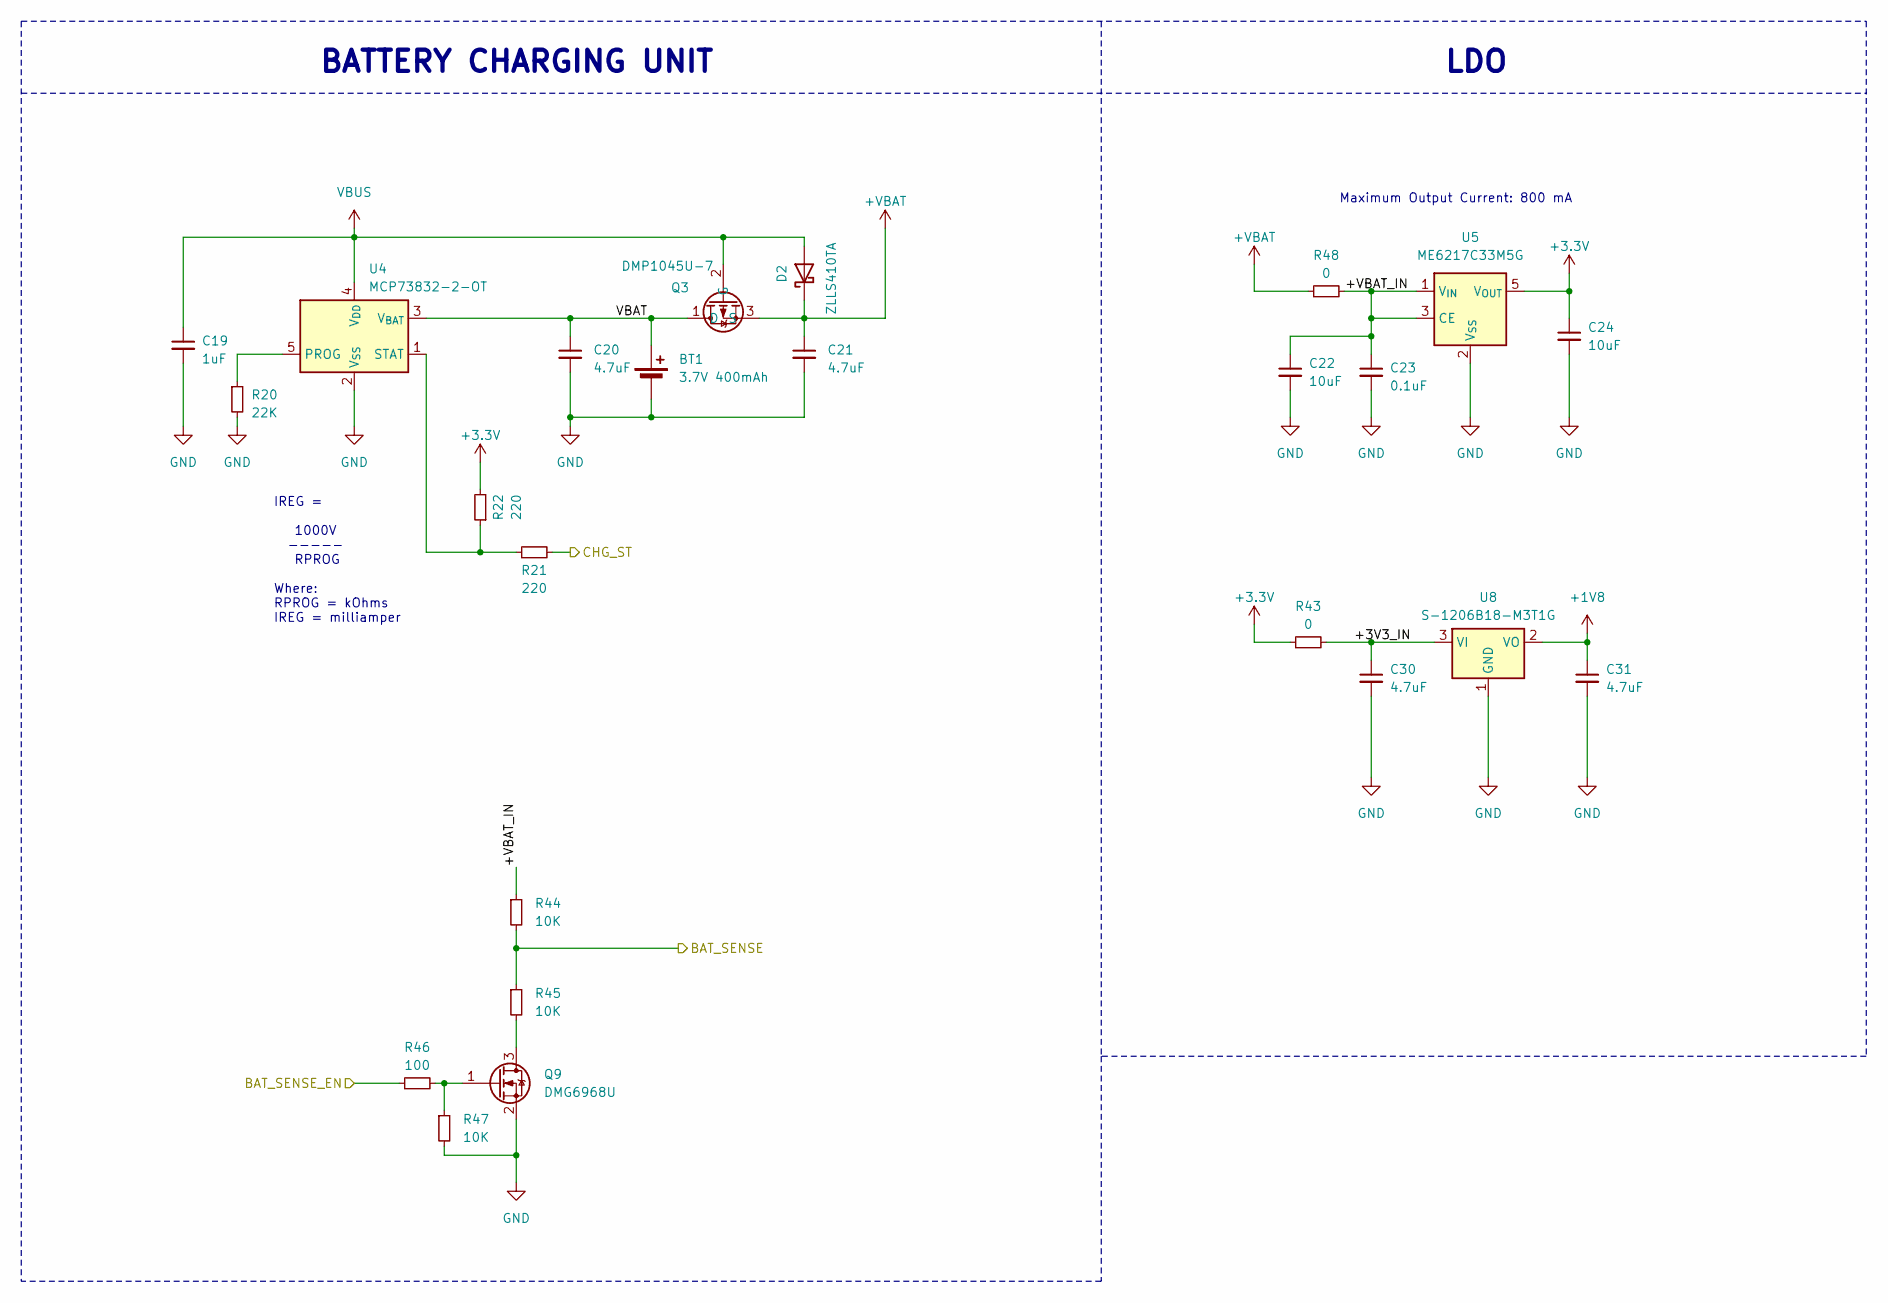
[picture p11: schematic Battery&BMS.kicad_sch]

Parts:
BT1: 3.7V 400mAh; WLY902025
C19: 1uF; C_0603_1608Metric
C20, C21, C30, C31: 4.7uF; C_0603_1608Metric
C22: 10uF; C_0402_1005Metric_Pad0.74x0.62mm_HandSolder
C23: 0.1uF; C_0402_1005Metric_Pad0.74x0.62mm_HandSolder
C24: 10uF; C_0603_1608Metric
D2: ZLLS410TA; D_SOD-323F
Q3: DMP1045U-7; SOT-23-3
Q9: DMG6968U; SOT-23
R20: 22K; R_0402_1005Metric_Pad0.72x0.64mm_HandSolder
R21, R22: 220; R_0402_1005Metric_Pad0.72x0.64mm_HandSolder
R43, R48: 0; R_0402_1005Metric_Pad0.72x0.64mm_HandSolder
R44, R45, R47: 10K; R_0402_1005Metric_Pad0.72x0.64mm_HandSolder
R46: 100; R_0402_1005Metric_Pad0.72x0.64mm_HandSolder
U4: MCP73832-2-OT; SOT-23-5
U5: ME6217C33M5G; SOT-23-5
U8: S-1206B18-M3T1G; SOT-23-3

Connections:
+1V8: C31.1, U8.2 (VO); also elsewhere on the board
+3.3V: C24.1, R22.2, R43.1, U5.5 (V_{OUT}); also elsewhere on the board
+VBAT: C21.1, D2.1 (K), Q3.3 (S), R48.1; also elsewhere on the board
/Battery&BMS/+3V3_IN: C30.1, R43.2, U8.3 (VI)
/Battery&BMS/+VBAT_IN: C22.1, C23.1, R44.1, R48.2, U5.1 (V_{IN}), U5.3 (CE)
/Battery&BMS/BAT_SENSE_EN: R46.1; also elsewhere on the board
/Battery&BMS/CHG_ST: R21.2; also elsewhere on the board
/Battery&BMS/VBAT: BT1.1 (+), C20.1, Q3.1 (D), U4.3 (V_{BAT})
/ESP32/BAT_VSENSE: R44.2, R45.1; also elsewhere on the board
GND: BT1.2 (-), C19.2, C20.2, C21.2, C22.2, C23.2, C24.2, C30.2, C31.2, Q9.2 (S), R20.2, R47.2, U4.2 (V_{SS}), U5.2 (V_{SS}), U8.1 (GND); also elsewhere on the board
unnamed: Q9.3 (D), R45.2
unnamed: Q9.1 (G), R46.2, R47.1
unnamed: R20.1, U4.5 (PROG)
unnamed: R21.1, R22.1, U4.1 (STAT)
VBUS: C19.1, D2.2 (A), Q3.2 (G), U4.4 (V_{DD}); also elsewhere on the board

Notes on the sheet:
Maximum Output Current: 800 mA
LDO
BATTERY CHARGING UNIT
IREG = 1000V ----- RPROG Where: RPROG = kOhms IREG = milliamper

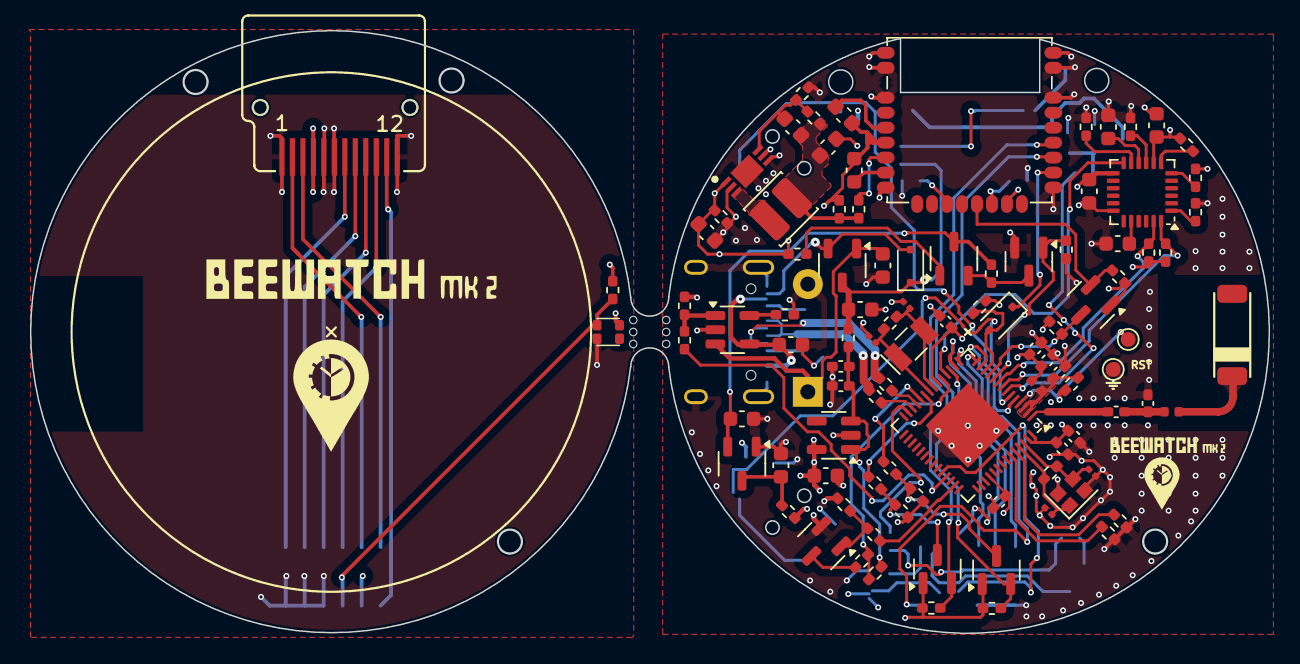
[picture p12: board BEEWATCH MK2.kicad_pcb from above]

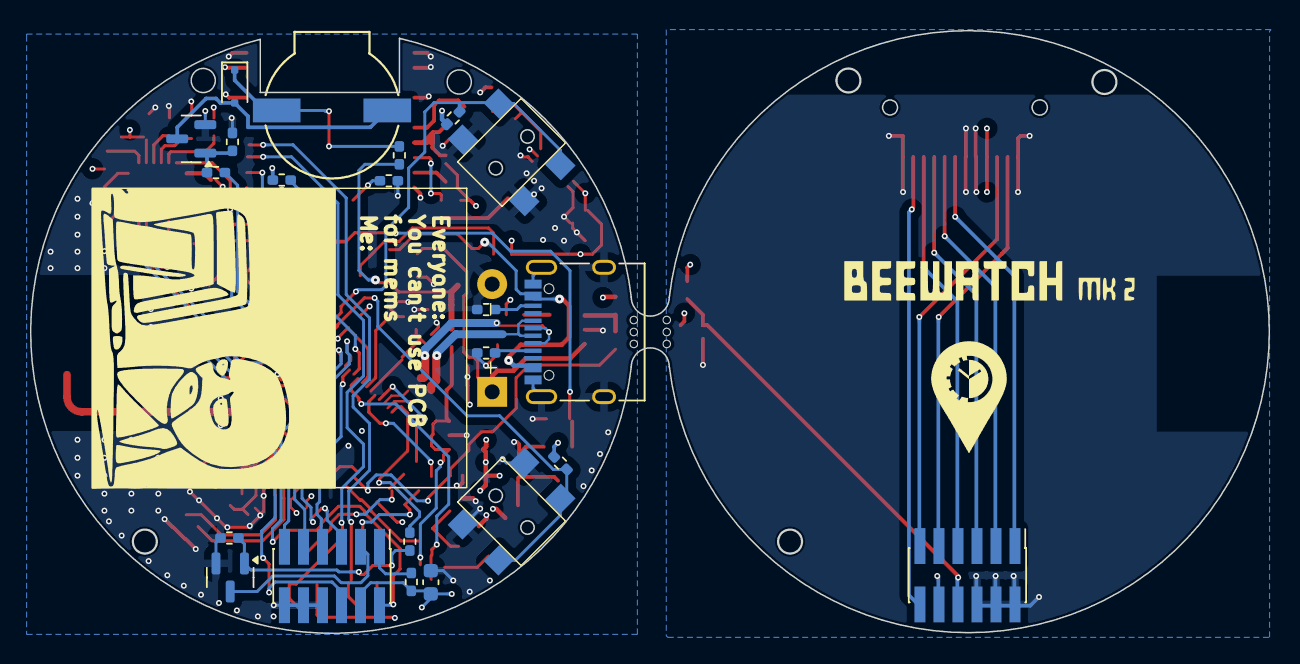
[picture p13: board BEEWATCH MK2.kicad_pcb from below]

Board: 4 copper layers, 82.7 x 40.3 mm, 122 parts (24 on the bottom side), 90 nets.

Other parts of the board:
D1: WS2812B-0807; XL-0807RGBC-WS2812B
DS1: GC9A01; GC9A01_BOTTOM
J4: Conn_02x06_Odd_Even; PinHeader_2x06_P1.27mm_Vertical_SMD
R6: 1K; R_0402_1005Metric_Pad0.72x0.64mm_HandSolder
meme_2: LOGO; meme_2
mouse-bite-2.54mm-slot: VAL**; mouse-bite-2.54mm-slot

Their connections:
/Display board/3V3: D1.1 (VDD), DS1.4 (VDD), J4.10, R6.2
/Display board/CS: DS1.8 (~CS), J4.3
/Display board/D/C: DS1.7 (D/C), J4.1
/Display board/LED_A: DS1.3 (LEDA), J4.11
/Display board/LED_K: DS1.2 (LEDK), J4.9
/Display board/RST: DS1.11 (~RESET), J4.12
/Display board/SCK: DS1.9 (SCK), J4.5
/Display board/SDI: DS1.10 (SDI), J4.7
/Display board/_GND: D1.3 (VSS), DS1.1 (GND), DS1.5 (GND), DS1.6 (GND), DS1.12 (GND), J4.2, J4.4, J4.6
/Display board/_LED: D1.2 (DOUT), J4.8, R6.1

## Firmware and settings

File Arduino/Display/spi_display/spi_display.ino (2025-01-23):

#include "SPI.h"
#include "Adafruit_GFX.h"
#include "Adafruit_GC9A01A.h"

#define TFT_DC 9
#define TFT_CS 10

// Hardware SPI on Feather or other boards
Adafruit_GC9A01A tft(TFT_CS, TFT_DC);

void setup() {
  Serial.begin(9600);
  Serial.println("GC9A01A Test!");

  tft.begin();

  Serial.println(F("Benchmark                Time (microseconds)"));
  delay(10);
  Serial.print(F("Screen fill              "));
  Serial.println(testFillScreen());
  delay(500);

  Serial.print(F("Text                     "));
  Serial.println(testText());
  delay(3000);

  Serial.print(F("Lines                    "));
  Serial.println(testLines(GC9A01A_CYAN));
  delay(500);

  Serial.print(F("Horiz/Vert Lines         "));
  Serial.println(testFastLines(GC9A01A_RED, GC9A01A_BLUE));
  delay(500);

  Serial.print(F("Rectangles (outline)     "));
  Serial.println(testRects(GC9A01A_GREEN));
  delay(500);

  Serial.print(F("Rectangles (filled)      "));
  Serial.println(testFilledRects(GC9A01A_YELLOW, GC9A01A_MAGENTA));
  delay(500);

  Serial.print(F("Circles (filled)         "));
  Serial.println(testFilledCircles(10, GC9A01A_MAGENTA));

  Serial.print(F("Circles (outline)        "));
  Serial.println(testCircles(10, GC9A01A_WHITE));
  delay(500);

  Serial.print(F("Triangles (outline)      "));
  Serial.println(testTriangles());
  delay(500);

  Serial.print(F("Triangles (filled)       "));
  Serial.println(testFilledTriangles());
  delay(500);

  Serial.print(F("Rounded rects (outline)  "));
  Serial.println(testRoundRects());
  delay(500);

  Serial.print(F("Rounded rects (filled)   "));
  Serial.println(testFilledRoundRects());
  delay(500);

  Serial.println(F("Done!"));
}

void loop(void) {
  for(uint8_t rotation=0; rotation<4; rotation++) {
    tft.setRotation(rotation);
    testText();
    delay(1000);
  }
}

unsigned long testFillScreen() {
  unsigned long start = micros();
  tft.fillScreen(GC9A01A_BLACK);
  yield();
  tft.fillScreen(GC9A01A_RED);
  yield();
  tft.fillScreen(GC9A01A_GREEN);
  yield();
  tft.fillScreen(GC9A01A_BLUE);
  yield();
  tft.fillScreen(GC9A01A_BLACK);
  yield();
  return micros() - start;
}

unsigned long testText() {
  tft.fillScreen(GC9A01A_BLACK);
  unsigned long start = micros();
  tft.setCursor(0, 0);
  tft.setTextColor(GC9A01A_WHITE);  tft.setTextSize(1);
  tft.println("Hello World!");
  tft.setTextColor(GC9A01A_YELLOW); tft.setTextSize(2);
  tft.println(1234.56);
  tft.setTextColor(GC9A01A_RED);    tft.setTextSize(3);
  tft.println(0xDEADBEEF, HEX);
  tft.println();
  tft.setTextColor(GC9A01A_GREEN);
  tft.setTextSize(5);
  tft.println("Groop");
  tft.setTextSize(2);
  tft.println("I implore thee,");
  tft.setTextSize(1);
  tft.println("my foonting turlingdromes.");
  tft.println("And hooptiously drangle me");
  tft.println("with crinkly bindlewurdles,");
  tft.println("Or I will rend thee");
  tft.println("in the gobberwarts");
  tft.println("with my blurglecruncheon,");
  tft.println("see if I don't!");
  return micros() - start;
}

unsigned long testLines(uint16_t color) {
  unsigned long start, t;
  int           x1, y1, x2, y2,
                w = tft.width(),
                h = tft.height();

  tft.fillScreen(GC9A01A_BLACK);
  yield();

  x1 = y1 = 0;
  y2    = h - 1;
  start = micros();
  for(x2=0; x2<w; x2+=6) tft.drawLine(x1, y1, x2, y2, color);
  x2    = w - 1;
  for(y2=0; y2<h; y2+=6) tft.drawLine(x1, y1, x2, y2, color);
  t     = micros() - start; // fillScreen doesn't count against timing

  yield();
  tft.fillScreen(GC9A01A_BLACK);
  yield();

  x1    = w - 1;
  y1    = 0;
  y2    = h - 1;
  start = micros();
  for(x2=0; x2<w; x2+=6) tft.drawLine(x1, y1, x2, y2, color);
  x2    = 0;
  for(y2=0; y2<h; y2+=6) tft.drawLine(x1, y1, x2, y2, color);
  t    += micros() - start;

  yield();
  tft.fillScreen(GC9A01A_BLACK);
  yield();

  x1    = 0;
  y1    = h - 1;
  y2    = 0;
  start = micros();
  for(x2=0; x2<w; x2+=6) tft.drawLine(x1, y1, x2, y2, color);
  x2    = w - 1;
  for(y2=0; y2<h; y2+=6) tft.drawLine(x1, y1, x2, y2, color);
  t    += micros() - start;

  yield();
  tft.fillScreen(GC9A01A_BLACK);
  yield();

  x1    = w - 1;
  y1    = h - 1;
  y2    = 0;
  start = micros();
  for(x2=0; x2<w; x2+=6) tft.drawLine(x1, y1, x2, y2, color);
  x2    = 0;
  for(y2=0; y2<h; y2+=6) tft.drawLine(x1, y1, x2, y2, color);

  yield();
  return micros() - start;
}

unsigned long testFastLines(uint16_t color1, uint16_t color2) {
  unsigned long start;
  int           x, y, w = tft.width(), h = tft.height();

  tft.fillScreen(GC9A01A_BLACK);
  start = micros();
  for(y=0; y<h; y+=5) tft.drawFastHLine(0, y, w, color1);
  for(x=0; x<w; x+=5) tft.drawFastVLine(x, 0, h, color2);

  return micros() - start;
}

unsigned long testRects(uint16_t color) {
  unsigned long start;
  int           n, i, i2,
                cx = tft.width()  / 2,
                cy = tft.height() / 2;

  tft.fillScreen(GC9A01A_BLACK);
  n     = min(tft.width(), tft.height());
  start = micros();
  for(i=2; i<n; i+=6) {
    i2 = i / 2;
    tft.drawRect(cx-i2, cy-i2, i, i, color);
  }

  return micros() - start;
}

unsigned long testFilledRects(uint16_t color1, uint16_t color2) {
  unsigned long start, t = 0;
  int           n, i, i2,
                cx = tft.width()  / 2 - 1,
                cy = tft.height() / 2 - 1;

  tft.fillScreen(GC9A01A_BLACK);
  n = min(tft.width(), tft.height());
  for(i=n; i>0; i-=6) {
    i2    = i / 2;
    start = micros();
    tft.fillRect(cx-i2, cy-i2, i, i, color1);
    t    += micros() - start;
    // Outlines are not included in timing results
    tft.drawRect(cx-i2, cy-i2, i, i, color2);
    yield();
  }

  return t;
}

unsigned long testFilledCircles(uint8_t radius, uint16_t color) {
  unsigned long start;
  int x, y, w = tft.width(), h = tft.height(), r2 = radius * 2;

  tft.fillScreen(GC9A01A_BLACK);
  start = micros();
  for(x=radius; x<w; x+=r2) {
    for(y=radius; y<h; y+=r2) {
      tft.fillCircle(x, y, radius, color);
    }
  }

  return micros() - start;
}

unsigned long testCircles(uint8_t radius, uint16_t color) {
  unsigned long start;
  int           x, y, r2 = radius * 2,
                w = tft.width()  + radius,
                h = tft.height() + radius;

  // Screen is not cleared for this one -- this is
  // intentional and does not affect the reported time.
  start = micros();
  for(x=0; x<w; x+=r2) {
    for(y=0; y<h; y+=r2) {
      tft.drawCircle(x, y, radius, color);
    }
  }

  return micros() - start;
}

unsigned long testTriangles() {
  unsigned long start;
  int           n, i, cx = tft.width()  / 2 - 1,
                      cy = tft.height() / 2 - 1;

  tft.fillScreen(GC9A01A_BLACK);
  n     = min(cx, cy);
  start = micros();
  for(i=0; i<n; i+=5) {
    tft.drawTriangle(
      cx    , cy - i, // peak
      cx - i, cy + i, // bottom left
      cx + i, cy + i, // bottom right
      tft.color565(i, i, i));
  }

  return micros() - start;
}

unsigned long testFilledTriangles() {
  unsigned long start, t = 0;
  int           i, cx = tft.width()  / 2 - 1,
                   cy = tft.height() / 2 - 1;

  tft.fillScreen(GC9A01A_BLACK);
  start = micros();
  for(i=min(cx,cy); i>10; i-=5) {
    start = micros();
    tft.fillTriangle(cx, cy - i, cx - i, cy + i, cx + i, cy + i,
      tft.color565(0, i*10, i*10));
    t += micros() - start;
    tft.drawTriangle(cx, cy - i, cx - i, cy + i, cx + i, cy + i,
      tft.color565(i*10, i*10, 0));
    yield();
  }

  return t;
}

unsigned long testRoundRects() {
  unsigned long start;
  int           w, i, i2,
                cx = tft.width()  / 2 - 1,
                cy = tft.height() / 2 - 1;

  tft.fillScreen(GC9A01A_BLACK);
  w     = min(tft.width(), tft.height());
  start = micros();
  for(i=0; i<w; i+=6) {
    i2 = i / 2;
    tft.drawRoundRect(cx-i2, cy-i2, i, i, i/8, tft.color565(i, 0, 0));
  }

  return micros() - start;
}

unsigned long testFilledRoundRects() {
  unsigned long start;
  int           i, i2,
                cx = tft.width()  / 2 - 1,
                cy = tft.height() / 2 - 1;

  tft.fillScreen(GC9A01A_BLACK);
  start = micros();
  for(i=min(tft.width(), tft.height()); i>20; i-=6) {
    i2 = i / 2;
    tft.fillRoundRect(cx-i2, cy-i2, i, i, i/8, tft.color565(0, i, 0));
    yield();
  }

  return micros() - start;
}

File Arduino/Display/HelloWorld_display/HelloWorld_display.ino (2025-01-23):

/*******************************************************************************
 * Start of Arduino_GFX setting
 *
 * Arduino_GFX try to find the settings depends on selected board in Arduino IDE
 * Or you can define the display dev kit not in the board list
 * Defalult pin list for non display dev kit:
 * Arduino Nano, Micro and more: CS:  9, DC:  8, RST:  7, BL:  6, SCK: 13, MOSI: 11, MISO: 12
 * ESP32 various dev board     : CS:  5, DC: 27, RST: 33, BL: 22, SCK: 18, MOSI: 23, MISO: nil
 * ESP32-C3 various dev board  : CS:  7, DC:  2, RST:  1, BL:  3, SCK:  4, MOSI:  6, MISO: nil
 * ESP32-S2 various dev board  : CS: 34, DC: 38, RST: 33, BL: 21, SCK: 36, MOSI: 35, MISO: nil
 * ESP32-S3 various dev board  : CS: 40, DC: 41, RST: 42, BL: 48, SCK: 36, MOSI: 35, MISO: nil
 * ESP8266 various dev board   : CS: 15, DC:  4, RST:  2, BL:  5, SCK: 14, MOSI: 13, MISO: 12
 * Raspberry Pi Pico dev board : CS: 17, DC: 27, RST: 26, BL: 28, SCK: 18, MOSI: 19, MISO: 16
 * RTL8720 BW16 old patch core : CS: 18, DC: 17, RST:  2, BL: 23, SCK: 19, MOSI: 21, MISO: 20
 * RTL8720_BW16 Official core  : CS:  9, DC:  8, RST:  6, BL:  3, SCK: 10, MOSI: 12, MISO: 11
 * RTL8722 dev board           : CS: 18, DC: 17, RST: 22, BL: 23, SCK: 13, MOSI: 11, MISO: 12
 * RTL8722_mini dev board      : CS: 12, DC: 14, RST: 15, BL: 13, SCK: 11, MOSI:  9, MISO: 10
 * Seeeduino XIAO dev board    : CS:  3, DC:  2, RST:  1, BL:  0, SCK:  8, MOSI: 10, MISO:  9
 * Teensy 4.1 dev board        : CS: 39, DC: 41, RST: 40, BL: 22, SCK: 13, MOSI: 11, MISO: 12
 ******************************************************************************/
#include <Arduino_GFX_Library.h>
#define GFX_BL 7 // default backlight pin, you may replace DF_GFX_BL to actual backlight pin
//.isr_cpu_id = 0, // Use CPU 0 as default
/* More dev device declaration: https://github.com/moononournation/Arduino_GFX/wiki/Dev-Device-Declaration */
#if defined(DISPLAY_DEV_KIT)
Arduino_GFX *gfx = create_default_Arduino_GFX();
#else /* !defined(DISPLAY_DEV_KIT) */

/* More data bus class: https://github.com/moononournation/Arduino_GFX/wiki/Data-Bus-Class */
Arduino_DataBus *bus = new Arduino_ESP32SPI(9 /* DC */, 10 /* CS */, 12 /* SCK */, 11 /* MOSI */, GFX_NOT_DEFINED /* MISO */);

/* More display class: https://github.com/moononournation/Arduino_GFX/wiki/Display-Class */
Arduino_GFX *gfx = new Arduino_GC9A01(bus, 8 /* RST */, 3 /* rotation */, true /* IPS */);

#endif /* !defined(DISPLAY_DEV_KIT) */
/*******************************************************************************
 * End of Arduino_GFX setting
 ******************************************************************************/

void setup(void)
{
  Serial.begin(115200);
  // Serial.setDebugOutput(true);
  // while(!Serial);
  Serial.println("Arduino_GFX Hello World example");

#ifdef GFX_EXTRA_PRE_INIT
  GFX_EXTRA_PRE_INIT();
#endif

  // Init Display
  if (!gfx->begin())
  {
    Serial.println("gfx->begin() failed!");
  }
  gfx->fillScreen(BLACK);

#ifdef GFX_BL
  pinMode(GFX_BL, OUTPUT);
  digitalWrite(GFX_BL, HIGH);
#endif

  gfx->setCursor(10, 10);
  gfx->setTextColor(RED);
  gfx->println("Hello World!");

  delay(5000); // 5 seconds
}

void loop()
{
  gfx->setCursor(random(gfx->width()), random(gfx->height()));
  gfx->setTextColor(random(0xffff), random(0xffff));
  gfx->setTextSize(random(6) /* x scale */, random(6) /* y scale */, random(2) /* pixel_margin */);
  gfx->println("Hello World!");

  delay(10); // 1 second
}

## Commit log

2023-03-09 working on schematics
    [BEEWATCH.kicad_pcb, BEEWATCH.kicad_sch, Battery&BMS.kicad_sch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]
2023-03-09 Inverted F Antenna designed
    [BEEWATCH.kicad_pcb, BEEWATCH.kicad_sch, Battery&BMS.kicad_sch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]
2023-03-09 Minor edits in IFA
    [BEEWATCH.kicad_sch, Battery&BMS.kicad_sch, Display.kicad_sch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]
2023-03-10 GPS Removed
    GPS is expensive and difficult to find small factor foot print. So No GPS function
    [Battery&BMS.kicad_sch, Display.kicad_sch, GPS.kicad_sch]
2023-03-10 GPS Removed
    [BEEWATCH.kicad_sch, ESP32.kicad_sch]
2023-03-13 Plan to add GPS
    [BEEWATCH.kicad_sch, Battery&BMS.kicad_sch, Display.kicad_sch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]
2023-03-13 Components selections
    [BEEWATCH.kicad_sch, Battery&BMS.kicad_sch, Display.kicad_sch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]
2023-03-13 Save Kicad files
    [BEEWATCH.kicad_pcb, Battery&BMS.kicad_sch, Display.kicad_sch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]
2023-03-21 ESP32 Symbol minor edit
2023-03-21 Insufficient GPIOs planning to add/C MUX or MCU
    [BEEWATCH.kicad_sch, Battery&BMS.kicad_sch, ESP32.kicad_sch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]
2023-05-08 planning to shift to ESP32-D0WDQ6
    [BEEWATCH.kicad_sch, Battery&BMS.kicad_sch, Display.kicad_sch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]
2023-05-20 Added specification excel
    [BEEWATCH.kicad_pcb, BEEWATCH.kicad_sch, Battery&BMS.kicad_sch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]
2025-01-23 Kicad design is ongoing
    [3d buzzer.step, BATTERY-BodyFillet002.step, BATTERY.FCStd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]
2025-01-26 Rough layout placement
    [BEEWATCH MK3.kicad_pcb, BEEWATCH MK3.kicad_sch, BEEWATCH MK3.step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]
2025-01-26 Minor changes in the footprint lib
    [BEEWATCH MK3.kicad_pcb]
2025-01-26 Added QFN 3D files
    [QFN-16 (4x4x0.9).iges, QFN-16 (4x4x0.9).step, QFN-20 (4x4x0.9).iges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]
2025-02-14 Update schema
    [ANT-BodyPad.step, ANT.FCStd, BEEWATCH MK3.kicad_pcb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]
2025-02-17 Schematic changes
    [Battery&BMS.kicad_sch, Display.kicad_sch, ESP32.kicad_sch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]
2025-02-18 GNSS level shifter floating voltage needs to be fix
    [Battery&BMS.kicad_sch, ESP32.kicad_sch, RYS8830.kicad_sch]
2025-02-19 Added Buzzer flyback diode
    [BEEWATCH MK3.kicad_pcb, Battery&BMS.kicad_sch, ESP32.kicad_sch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]
2025-02-19 Updated with sub module lib
    [BEEWATCH MK3.kicad_pcb, Battery&BMS.kicad_sch, ESP32.kicad_sch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]
2025-02-20 Lib Integration almost done
    [3d buzzer.step, ANT-BodyPad.step, ANT.FCStd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]
2025-02-20 minor change in ESP32
    [BEEWATCH MK3.kicad_pcb, ESP32.kicad_sch]
2025-02-20 minor changes
    [BEEWATCH MK3.kicad_pcb]
2025-02-20 NAME changes
    [USB_type_C_smd_24p.stp]
2025-02-24 Updated to KiCad 9!
    [BEEWATCH MK2.kicad_pcb, BEEWATCH MK2.kicad_sch, Battery&BMS.kicad_sch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]
2025-02-27 ERC Checking
    [BEEWATCH MK2.kicad_pcb, Battery&BMS.kicad_sch, DISPLAY.kicad_sch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]
2025-02-27 Addd Buck
2025-02-27 ERC going on anf All Lib issue is fixed
    [BEEWATCH MK2.kicad_pcb, Battery&BMS.kicad_sch, ESP32.kicad_sch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]
2025-02-28 Pending task Crystal footprint
    [BEEWATCH MK2.kicad_pcb, ESP32.kicad_sch]
2025-03-03 Crystal footprint fixed
    [BEEWATCH MK2.kicad_pcb, ESP32.kicad_sch]
2025-03-03 Deep optmizing the Layout
    [BEEWATCH MK2.kicad_pcb]
2025-03-04 Deep optmization 80% completed
    [BEEWATCH MK2.kicad_pcb, Battery&BMS.kicad_sch]
2025-03-04 Deep optmization 90% completed
    [BEEWATCH MK2.kicad_pcb, Display.kicad_sch, ESP32.kicad_sch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]
2025-03-05 Changed +3V3 to +3.3V
    [RYS8830.kicad_sch]
2025-03-05 Deep optimization 100%
    [BEEWATCH MK2.kicad_pcb]
2025-03-06 Duplicate pin changed
    [ESP32.kicad_sch]
2025-03-06 Routing ongoing
    [BEEWATCH MK2.kicad_pcb]
2025-03-11 Layout ongoing
    [BEEWATCH MK2.kicad_pcb]
2025-03-13 Layout almost completed
    [BEEWATCH MK2.kicad_pcb]
2025-03-13 Added display board schema
    [BEEWATCH MK2.kicad_sch, Display.kicad_sch, Display_board.kicad_sch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]
2025-03-13 Somehow finished the layout, but deep optimization required
    [BEEWATCH MK2.kicad_pcb]
2025-03-20 Added SMA connector
    [ESP32.kicad_sch]
2025-03-20 Layout Finished but deep otimization required
    [BEEWATCH MK2.kicad_pcb]
2025-03-26 Removed SMA
    [BEEWATCH MK2.kicad_pcb]
2025-03-26 Need to update some values
    [ESP32.kicad_sch]
2025-04-12 Layout DRC ongoing
    [BEEWATCH MK2.kicad_pcb]
2025-04-12 Added net class colour
    [BEEWATCH MK2.kicad_pcb, ESP32.kicad_sch]
2025-04-12 Antenna layout completed
    [BEEWATCH MK2.kicad_pcb]
2025-04-12 Updated Antenna footprint
2025-04-13 Antenna and Schematic correction
    [BEEWATCH MK2.kicad_pcb, Battery&BMS.kicad_sch, ESP32.kicad_sch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]
2025-04-13 Updated submodule KiCadoodle to latest commit
2025-04-13 Hope this by next week gerbers will generate
    [BEEWATCH MK2.kicad_pcb, ESP32.kicad_sch, RYS8830.kicad_sch]
2025-04-13 Display holes added
    [BEEWATCH MK2.kicad_pcb]
2025-04-22 Added Panalized board file
    [BEEWATCH MK2.kicad_pcb]
2025-04-22 Updating MPN
    [Battery&BMS.kicad_sch, Display.kicad_sch, Display_board.kicad_sch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]
2025-04-23 PCB Updated
    [BEEWATCH MK2-drl_map.dxf, BEEWATCH MK2.kicad_pcb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]
2025-04-26 Added board2pdf config file
2025-04-26 Modified Assembly file
2025-04-30 PCB update
2025-05-08 Changing to FAB capability
    [BEEWATCH MK2-NPTH-drl_map.dxf, BEEWATCH MK2-PTH-drl_map.dxf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]
2025-05-14 Updated PCB file
2025-05-14 Removed old files
    [BEEWATCH MK2-NPTH-drl_map.dxf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]
2025-08-31 Hide MPN
    [BEEWATCH MK2.kicad_sch, Battery&BMS.kicad_sch, Display.kicad_sch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]
2025-12-04 Kicadoodle update......
